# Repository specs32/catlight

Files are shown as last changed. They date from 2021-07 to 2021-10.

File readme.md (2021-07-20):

# CATLight (Creativity Art Technology)

The new and shiny Flat Flashlight, now featuring:

- ESP32-S2
- MAX77751
- SK6812 + Cree J-Series
- IMU LSM6DS3
- 3000 mAh LiPo (11.5 Wh)
- more to come

Thank you and have a nice day !

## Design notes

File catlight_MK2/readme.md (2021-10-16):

# CATLight (Creativity Art Technology)

This is MARK 2 of the new and shiny ESP32-S2 driven flat flashlight (aka flatlight)

This is a close proximity Flashlight, it has no lense to focus a beam, but it smoothly lights up a wide field around you. I find it perfect for indoor usage (searching dark drawers in the cellar and so on, but it also lights your way to the shed at night..)

Features : 
- USB-C power delivery standard realized with a MAX77751 (fast charge + PD (boost mode 5V up to 1 Amp))
- ESP32-S2 with wifi etc...
- 1.2 " TFT SPI color display
- 1 IMU LSM6DS3 or LSM6DSM .. both will work with slight changes in the initialization
- 1 CREE XLAMP with a DIO5661 flash driver and protective lens (no focus) that delivers up to 1.5 Amps into the XLAMP.. makes for a nice foto flash ..
- 16 neopixels on there 2 rows by 8.. i think it is possible to realize a POV display with it since there also is a LSM6DS3 IMU on there.
- 10 Duris high power LEDs (100mA each) this is the main light source (300 mA J-Series are no longer available.. sadly !)
- 4 TEMP sensors on the light. 2 NTCs close to critical places (XLAMP and Duris LEDS) 1 in the ESP itself and on in the IMU.
- Battery Voltage measuring (resistor divider on analog 1)

### This Revision works ! 

... with no errors as far as I can see and test (I own no OSZI ;))

There is one thing though... the Antenna matching Network works better if you put a cap in series and the coil in the first place to ground. (swap C24 with L3)

This revision works with WLED beta 2 (0.13.0-b2) there are filesystem issues, but the default install seems to work and you can save the LED settings and power off / on again and it maintains theses settings even there is no "official" support for the ESP32-S2 yet.
MAYBE I will fork and branch and modify and write a usermod for wled in the future. Maybe...
For now there is rudimentary arduino firmware in the arduino folder.
There is a platformio_override.ini in the base Folder I used to compile WLED with in code OSS with platformio under arch linux.

#### WARNING !!! WARNING !!! WARNING !!! WARNING !!! WARNING !!! WARNING !!! WARNING !!! WARNING !!! 

DO NOT put too much capacitance on the LED side, it will mess with the soft latch ! 1µF per duris LED is sufficient and works.
If you put a lot of high value CAPs on the LED side you need to lower the value of R5. (1.2KΩ with 25 µF on the LED side. Flash and array)

the duris LEDs are mosfet driven and that is their ONE and ONLY current limiter, a duty cycle of 30 % on a full lipo makes a nice bright light.
if you pull up the mosfet with 100 % duty cycle it make a smoldered PCB with the LEDs falling off and molten solder dripping everywhere... 
probably a good idea to keep that in mind when fumbling with the firmware...
___

there is a footprint for additional flash memory with a solder bridge CS0/CS1 parallel to the internal flash. if you have an ESP32-S2 without flash you can put a flash chip here (AT256Q i think) please refer to the flash compatibility list for the ESP32-S2 on the espressif website.

wifi standby time with a genuine LIPO Battery is 60+ hours

USB-C fast charging works up to 2.5 Ampere !! (almost full in 60 minutes ;))
the MAX 77751 supports pass through and power delivery, so you can charge your phne on the light in an emerrgency !

Please keep in mind that this project is my private experiment and CC-BY-NC-SA !
If you blow up your toaster .. not my fault.

the overall development cost was 600 €, the cost per CATLight (PCB + parts + 3dprint) is around 50 € assembly time is 6-8 hours if you do it 100% by hand.

Have fun emitting Bosons of differend wavelength..

made with <3 btw!

#### Special thanks to Lisa who provided all the cat drawings !!!
___
___

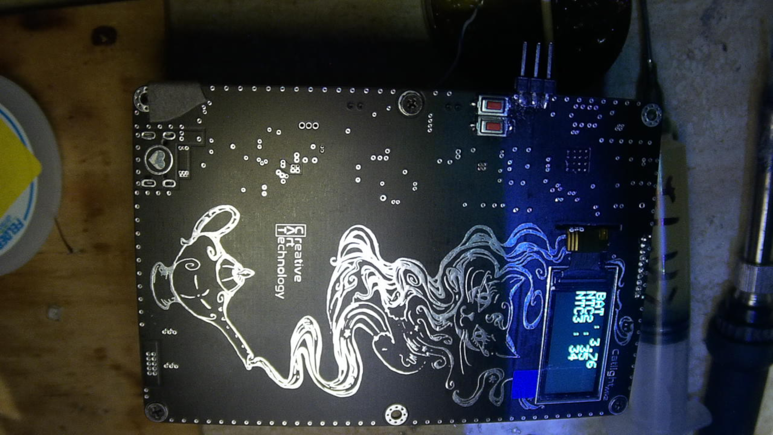
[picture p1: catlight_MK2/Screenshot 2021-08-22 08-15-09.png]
screen1

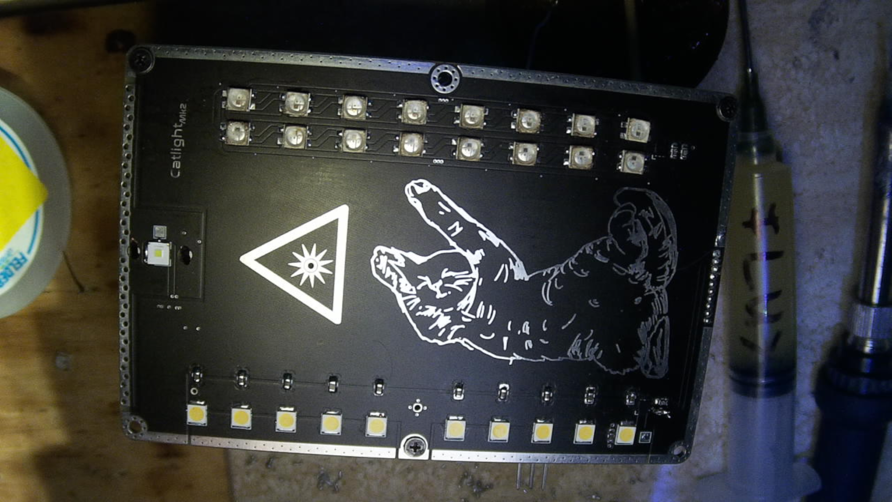
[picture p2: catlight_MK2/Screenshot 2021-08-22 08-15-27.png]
screen2

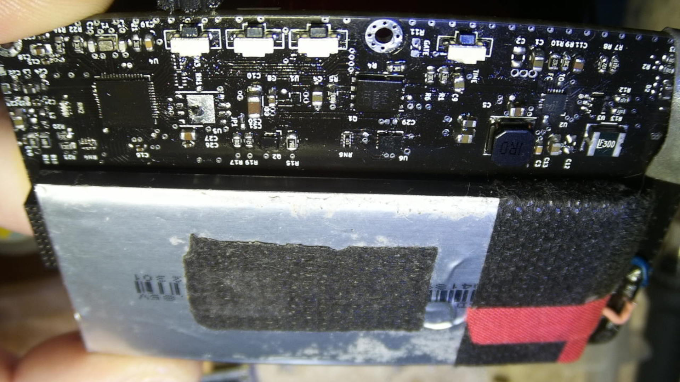
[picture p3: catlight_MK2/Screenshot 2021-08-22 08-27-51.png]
screen3

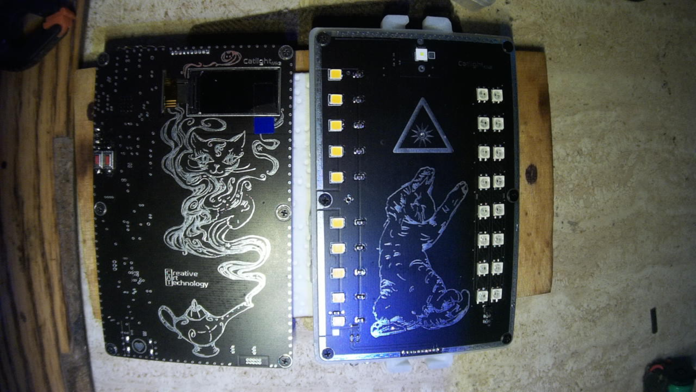
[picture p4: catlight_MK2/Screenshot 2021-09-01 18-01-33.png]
screen4


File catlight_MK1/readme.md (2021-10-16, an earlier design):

# CATLight (Creativity Art Technology)

This is MARK 1 of the new and shiny ESP32-S2 driven flat flashlight (aka flatlight)

The last flatlight revision was 19 ... I changed naming, and revision number from here on.

So this would be the flatlight REV 20

## This Revision contains multiple errors and has many features missing !!

### The first Pancake never gets right ;)

I release it anyways. Its just my dirty Sandbox to get some mud on my fingers !

thank you and have a nice day !

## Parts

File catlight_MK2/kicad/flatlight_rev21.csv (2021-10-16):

Source: | /home/jeez/Documents/kicad/PROJECTS/flatlight_rev21/flatlight_rev21.kicad_sch
Date: | Thu 26 Aug 2021 20:55:10 CEST
Tool: | Eeschema (5.99.0-11689-g04c6b79350)
Generator: | /usr/share/kicad-nightly/plugins/bom_csv_grouped_by_value_with_fp.py
Component Count: | 169
Ref | Qnty | Value | Cmp name | Footprint | Description | Vendor
BT1, | 1 | lipo_sams_BG930ABE | lipo_sams_BG930ABE | lt_foots:lipo_samsung_BG930ABE_double | Multiple-cell battery
C1, C2, C6, C12, C18, C23, C30, C31, C32, C33, C34, C35, C36, C37, C38, C39, | 16 | 10µF | C_Small | Capacitor_SMD:C_0805_2012Metric | Unpolarized capacitor, small symbol
C3, | 1 | 100nF | C | Capacitor_SMD:C_0603_1608Metric | Unpolarized capacitor
C4, C7, C8, C9, C19, C22, C27, | 7 | 1µF | C | Capacitor_SMD:C_0603_1608Metric | Unpolarized capacitor
C5, C11, | 2 | 2.2µF | C_Small | Capacitor_SMD:C_0603_1608Metric | Unpolarized capacitor, small symbol
C10, | 1 | 10µF | C_Small | Capacitor_SMD:C_1206_3216Metric_Pad1.33x1.80mm_HandSolder | Unpolarized capacitor, small symbol
C13, | 1 | 22µF | C | Capacitor_SMD:C_0805_2012Metric | Unpolarized capacitor
C14, C20, | 2 | 10pF | C_Small | Capacitor_SMD:C_0402_1005Metric | Unpolarized capacitor, small symbol
C15, C16, C21, C26, C28, C29, C49, | 7 | 100nF | C_Small | Capacitor_SMD:C_0402_1005Metric | Unpolarized capacitor, small symbol
C24, C25, | 2 | 4,7 pF | C | Capacitor_SMD:C_0402_1005Metric | Unpolarized capacitor
C46, | 1 | 22µF | C_Small | Capacitor_SMD:C_1206_3216Metric | Unpolarized capacitor, small symbol
C47, | 1 | 10µF | C_Small | Capacitor_SMD:C_1206_3216Metric | Unpolarized capacitor, small symbol
D1, | 1 | LED_ABRG | LED_ABRG | lt_foots:0606_ARGB_LED | RGB LED, anode/blue/red/green
D2, | 1 | ESD9B5.0ST5G | ESD9B5.0ST5G | Diode_SMD:D_0402_1005Metric_Pad0.77x0.64mm_HandSolder | ESD protection diode, 5.0Vrwm, SOD-923
D3, D4, D5, D6, D7, D8, D9, D10, D11, D12, D13, D14, D15, D16, D17, D18, | 16 | SK6812MINI | SK6812MINI | lt_foots:LED_SK6812MINI | RGB LED with integrated controller
D19, D20, D21, D22, D23, D24, D25, D26, D27, D28, | 10 | LED | LED | LED_SMD:LED_PLCC_2835 | Light emitting diode
D35, | 1 | LED_Cree_XPP | LED_Cree_XPP | LED_SMD:LED_Cree-XHP35
F1, | 1 | Polyfuse_Small | Polyfuse_Small | lt_foots:FUSE_littlefuse_2016-4.1x5.2mm | Resettable fuse, polymeric positive temperature coefficient, small symbol
FB1, | 1 | FerriteBead_Small | FerriteBead_Small | Resistor_SMD:R_0805_2012Metric_Pad1.20x1.40mm_HandSolder | Ferrite bead, small symbol
H1, H2, H3, H4, H5, H6, H15, H16, H17, H18, H19, H20, | 12 | MountingHole_Pad | MountingHole_Pad | MountingHole:MountingHole_2.2mm_M2_Pad_Via | Mounting Hole with connection
H7, | 1 | thole1 | MountingHole_Pad | lt_foots:plated_hole_1mm | Mounting Hole with connection
H14, | 1 | thole8 | MountingHole_Pad | lt_foots:plated_hole_1mm | Mounting Hole with connection
J1, | 1 | USB_C_Receptacle_USB2.0 | USB_C_Receptacle_USB2.0 | Connector_USB:USB_C_Receptacle_JAE_DX07S016JA1R1500 | USB 2.0-only Type-C Receptacle connector
J2, | 1 | G-T-R | Conn_01x03_Male | lt_foots:01x03_smd_1mmx2mm_pad | Generic connector, single row, 01x03, script generated (kicad-library-utils/schlib/autogen/connector/)
J3, | 1 | B2B_eside | Conn_01x10 | Connector_PinSocket_1.27mm:PinSocket_1x10_P1.27mm_Vertical | Generic connector, single row, 01x10, script generated (kicad-library-utils/schlib/autogen/connector/)
J4, | 1 | B2B_ledside | Conn_01x10 | Connector_PinHeader_1.27mm:PinHeader_1x10_P1.27mm_Vertical | Generic connector, single row, 01x10, script generated (kicad-library-utils/schlib/autogen/connector/)
JP1, | 1 | SolderJumper_3_Open | SolderJumper_3_Open | lt_foots:microbridge | Solder Jumper, 3-pole, open
L1, | 1 | 1µH | L_Ferrite_Small | Inductor_SMD:L_Taiyo-Yuden_NR-60xx | Inductor with ferrite core, small symbol
L2, | 1 | 1µH | L_Small | Inductor_SMD:L_0603_1608Metric | Inductor, small symbol
L3, | 1 | 1.8 nH | L_Small | Inductor_SMD:L_0603_1608Metric | Inductor, small symbol
L4, | 1 | 1µH | L_Ferrite_Small | Inductor_SMD:L_1008_2520Metric_Pad1.43x2.20mm_HandSolder | Inductor with ferrite core, small symbol
lense1, | 1 | Lense_Mount | heart | lt_foots:LENS_LEDIL_C12491_siri_diff
logo1, | 1 | logo_qrtag | logo_serialnumber | lt_foots:logo_QR_url_git_catlight
logo2, logo5, | 2 | logo_JLC | logo_contact | lt_foots:JLC-SERIAL
logo4, | 1 | logo_TIGER | logo_contact | lt_foots:LOGO_Tiger_1
logo6, | 1 | logo_esd | logo_contact | Symbol:ESD-Logo_6.6x6mm_SilkScreen
logo7, | 1 | logo_FIREFLY_lrg | logo_serialnumber | lt_foots:logo_firefly_40mm
logo8, | 1 | logo_heart | logo_contact | lt_foots:logo_heart3
logo9, | 1 | logo_LWarn | logo_serialnumber | lt_foots:logo_lightwarn_large
logo10, | 1 | logo_CATLIGHT | logo_contact | lt_foots:logo_catlightMK2_small
Q1, | 1 | DMC1016UPD | DMC1016UPD | lt_foots:PowerDI5060-8
Q2, Q3, Q4, | 3 | DMN2022-UFDF7 | DMN2022-UFDF7 | lt_foots:U-DFN2020-6 (Type F) | 0.2A Id, 200V Vds, N-Channel MOSFET, 2.6V Logic Level, TO-92
R1, R4, R14, R21, R22, | 5 | 10kΩ | R_Small | Resistor_SMD:R_0603_1608Metric | Resistor, small symbol
R2, R3, | 2 | 1KΩ | R_Small | Resistor_SMD:R_0603_1608Metric | Resistor, small symbol
R5, | 1 | 10kΩ (depending on caps) | R | Resistor_SMD:R_0603_1608Metric | Resistor
R6, | 1 | 100kΩ | R | Resistor_SMD:R_0603_1608Metric | Resistor
R7, R8, | 2 | 20kΩ | R_Small | Resistor_SMD:R_0603_1608Metric | Resistor, small symbol
R9, | 1 | 10KΩ(150mA_TO) | R_Small | Resistor_SMD:R_0603_1608Metric | Resistor, small symbol
R10, | 1 | 10KΩ(1.5A_FC) | R_Small | Resistor_SMD:R_0603_1608Metric | Resistor, small symbol
R11, | 1 | 0 Ω | R | Resistor_SMD:R_0603_1608Metric | Resistor
R12, R13, | 2 | 22Ω | R_Small | Resistor_SMD:R_0603_1608Metric | Resistor, small symbol
R15, | 1 | 14Ω | R | Resistor_SMD:R_0805_2012Metric | Resistor
R16, R18, R19, R25, R29, | 5 | 1MΩ | R | Resistor_SMD:R_0603_1608Metric | Resistor
R17, R24, R28, | 3 | 1kΩ | R | Resistor_SMD:R_0603_1608Metric | Resistor
R20, R23, | 2 | 10 kΩ | R | Resistor_SMD:R_0603_1608Metric | Resistor
R26, R27, | 2 | NTC 10 kΩ | R | Resistor_SMD:R_0603_1608Metric | Resistor
R30, | 1 | 37.5kΩ | R | Resistor_SMD:R_0603_1608Metric | Resistor
R31, | 1 | 12kΩ | R | Resistor_SMD:R_0603_1608Metric | Resistor
RN1, RN2, RN3, | 3 | 0Ω | R_Pack04 | lt_foots:R_Array_Concave_4x0402 | 4 resistor network, parallel topology
RN4, | 1 | 1kΩ | R_Pack04 | lt_foots:R_Array_Concave_4x0402 | 4 resistor network, parallel topology
RN6, | 1 | 10KΩ | R_Pack04 | lt_foots:R_Array_Concave_4x0402 | 4 resistor network, parallel topology
SW1, SW4, SW5, SW6, | 4 | BTN_PWR | nano_switc_with_mnt_pads-nicos-parts | lt_foots:white_nano_smd_switch
SW2, | 1 | BT | SW_Push | lt_foots:SW_SPST_EVQPE1 | Push button switch, generic, two pins
SW3, | 1 | RST | SW_Push | lt_foots:SW_SPST_EVQPE1 | Push button switch, generic, two pins
TFT1, | 1 | OLED_ST7735_0.9inch_SPI_13pin | OLED_ST7735_0.9inch_SPI_13pin | lt_foots:TFT_ST7735_0,96_160x80_folded
TP6, | 1 | ANT_H | TestPoint | TestPoint:TestPoint_Pad_1.0x1.0mm | test point
TP8, | 1 | ANT_GND | TestPoint | TestPoint:TestPoint_Pad_1.0x1.0mm | test point
TP9, TP10, | 2 | TestPoint | TestPoint | TestPoint:TestPoint_Pad_1.5x1.5mm | test point
TP11, TP12, | 2 | GND | TestPoint | TestPoint:TestPoint_Pad_1.0x1.0mm | test point
TP13, TP14, | 2 | +BATT | TestPoint | TestPoint:TestPoint_Pad_1.0x1.0mm | test point
U1, | 1 | NCP167-XDFN4 | NCP167-XDFN4 | Package_DFN_QFN:UDFN-4-1EP_1x1mm_P0.65mm_EP0.48x0.48mm
U2, | 1 | MAX77751 | MAX77751 | lt_foots:max77751
U3, | 1 | USBLC6-4SC6 | USBLC6-4SC6 | Package_TO_SOT_SMD:SOT-23-6 | Very low capacitance ESD protection diode, 4 data-line, SOT-23-6
U4, | 1 | ESP32-S2 | ESP32-S2 | lt_foots:QFN-56-1EP_7x7mm_P0.4mm_EP5.6x5.6mm_ThermalVias | RF Module, ESP32 SoC, Wi-Fi 802.11b/g/n, Bluetooth, BLE, 32-bit, 2.7-3.6V, external antenna, QFN-48
U5, | 1 | AT25xxx-MA | AT25xxx-MA | Package_SON:WSON-8-1EP_6x5mm_P1.27mm_EP3.4x4.3mm | Microchip SPI Serial EEPROM, DFN8
U6, | 1 | LSM6DS3 | LSM6DS3 | Package_LGA:Bosch_LGA-14_3x2.5mm_P0.5mm | I2C/SPI, iNEMO inertial module: always-on 3D accelerometer and 3D gyroscope
U7, | 1 | LDRV_DIO5180 | LDRV_DIO5180 | lt_foots:DFN-14-2x3mm
Y1, | 1 | 40MHz | Crystal_GND24_Small | lt_foots:Crystal_SMD_2016-4Pin_2.0x1.6mm_smallpads | Four pin crystal, GND on pins 2 and 4, small symbol

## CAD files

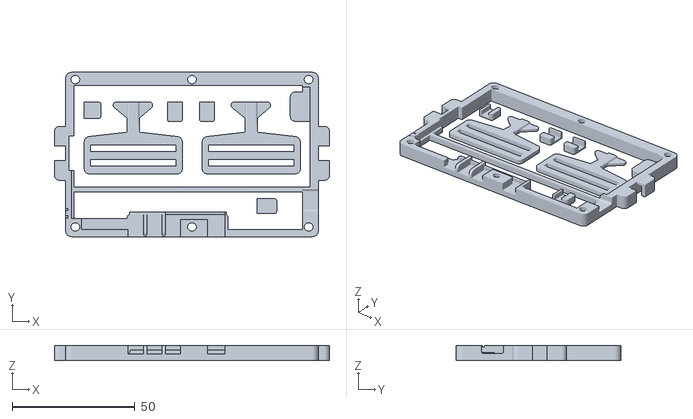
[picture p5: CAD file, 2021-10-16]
catlight_MK2/blender/catlight_frame_30.stl
112.0 x 67.0 x 6.00

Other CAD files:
catlight_MK2/blender/catlight_frame_30.blend

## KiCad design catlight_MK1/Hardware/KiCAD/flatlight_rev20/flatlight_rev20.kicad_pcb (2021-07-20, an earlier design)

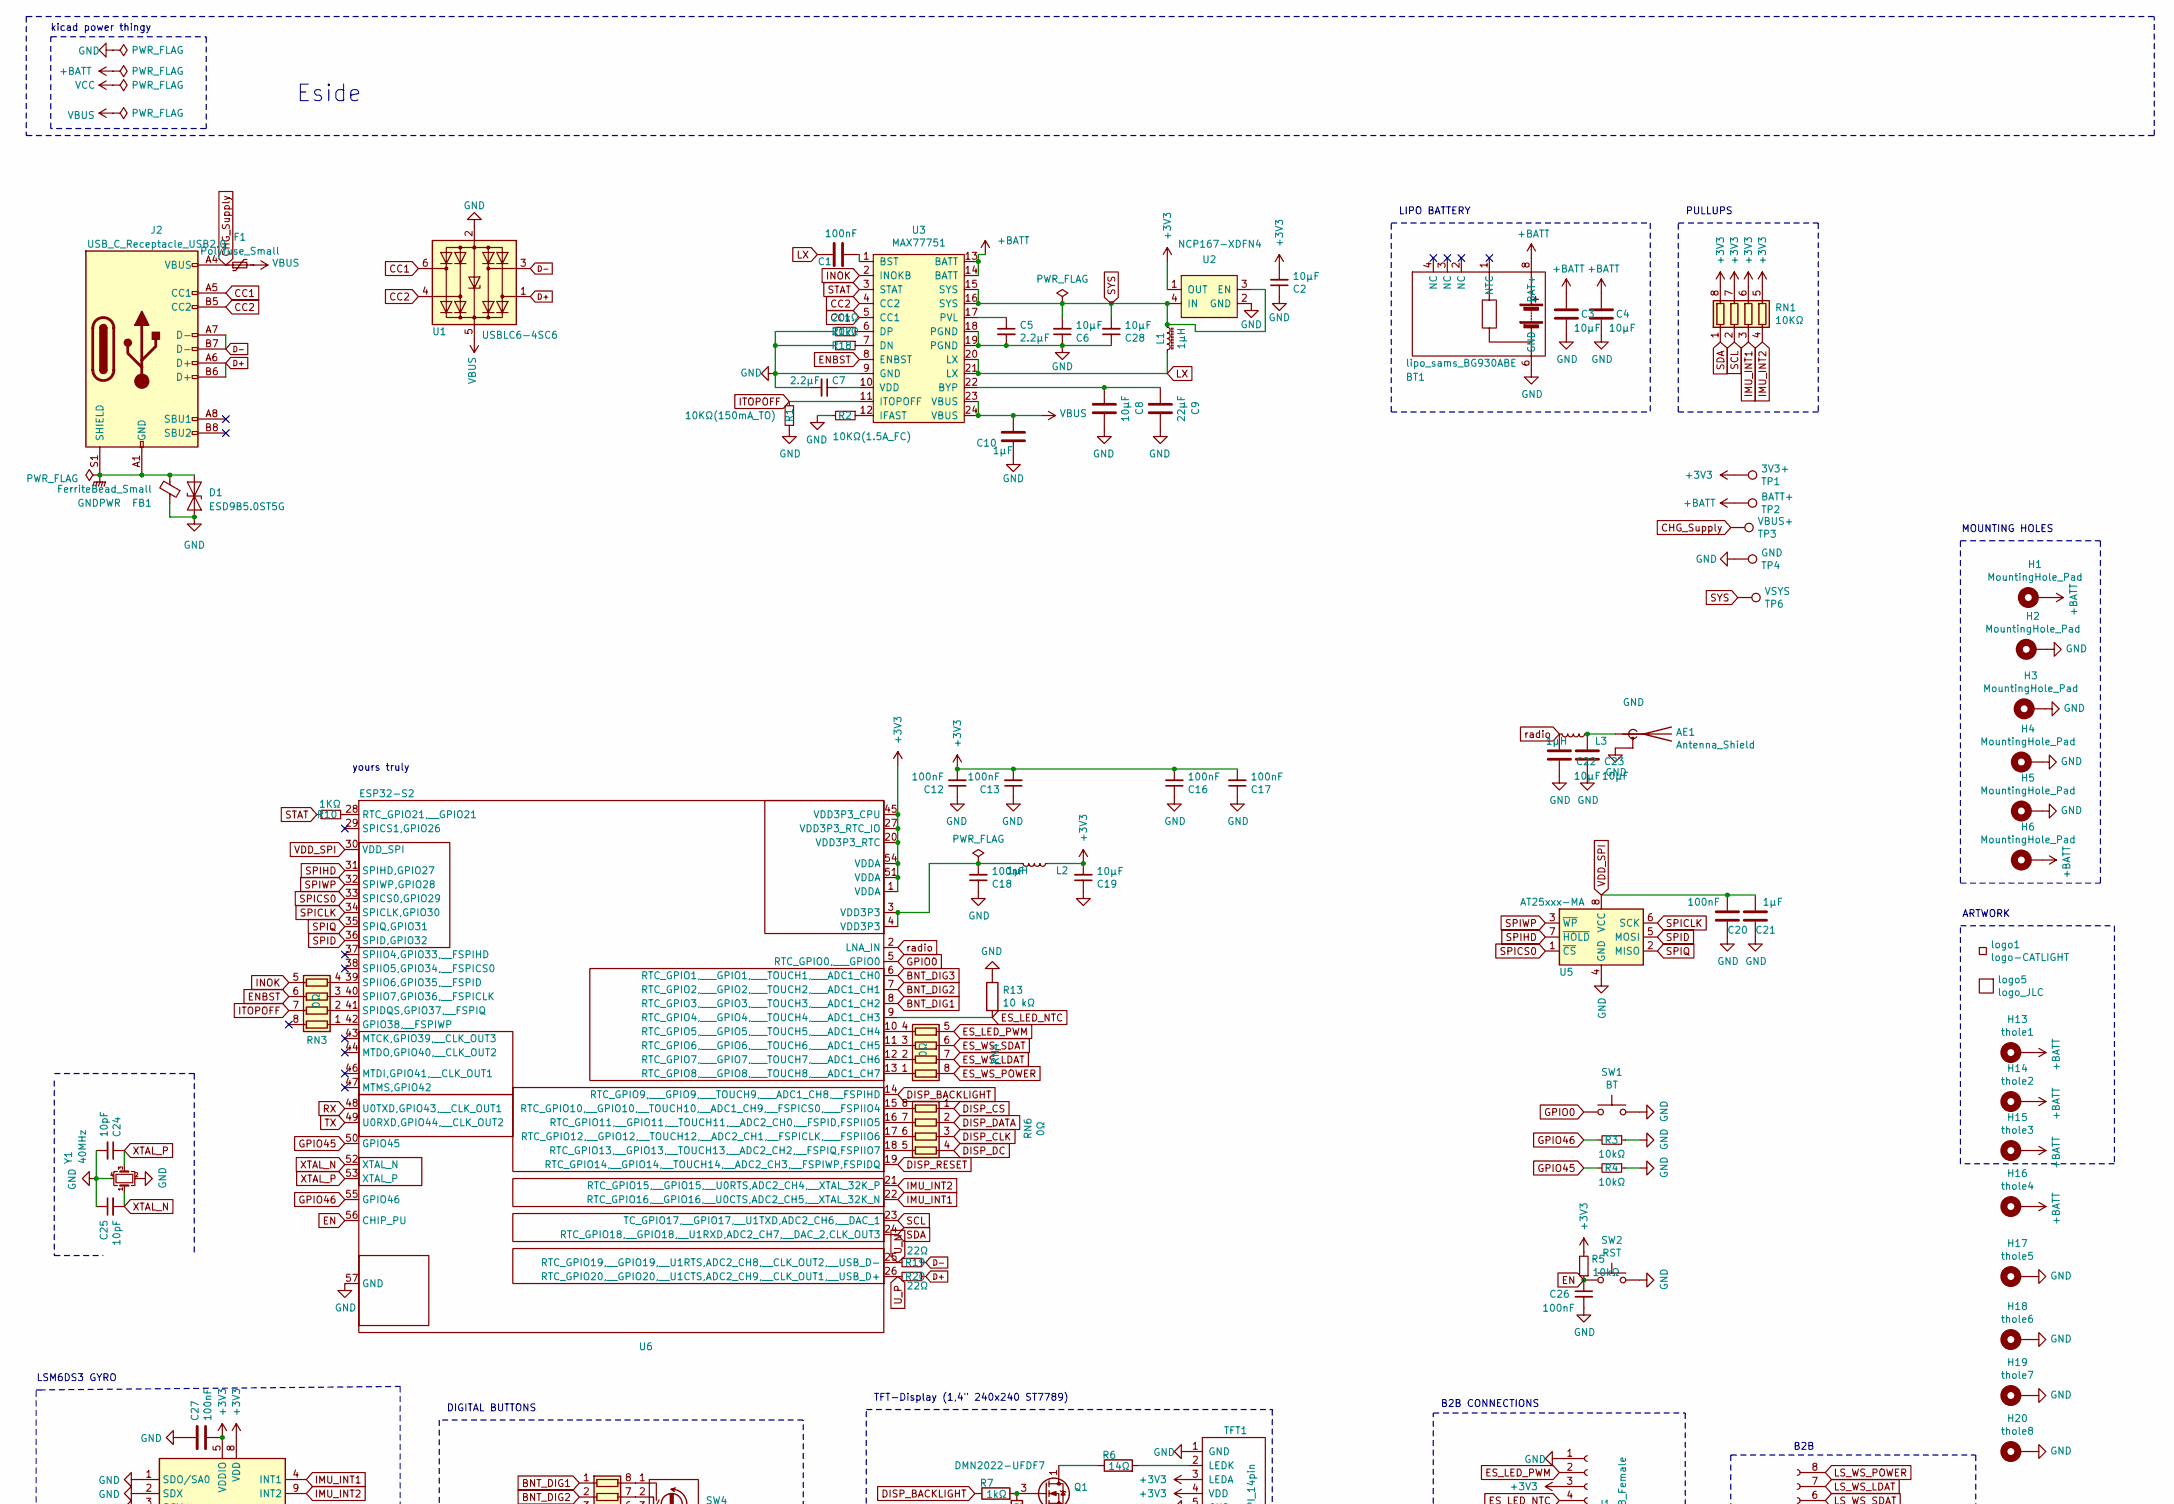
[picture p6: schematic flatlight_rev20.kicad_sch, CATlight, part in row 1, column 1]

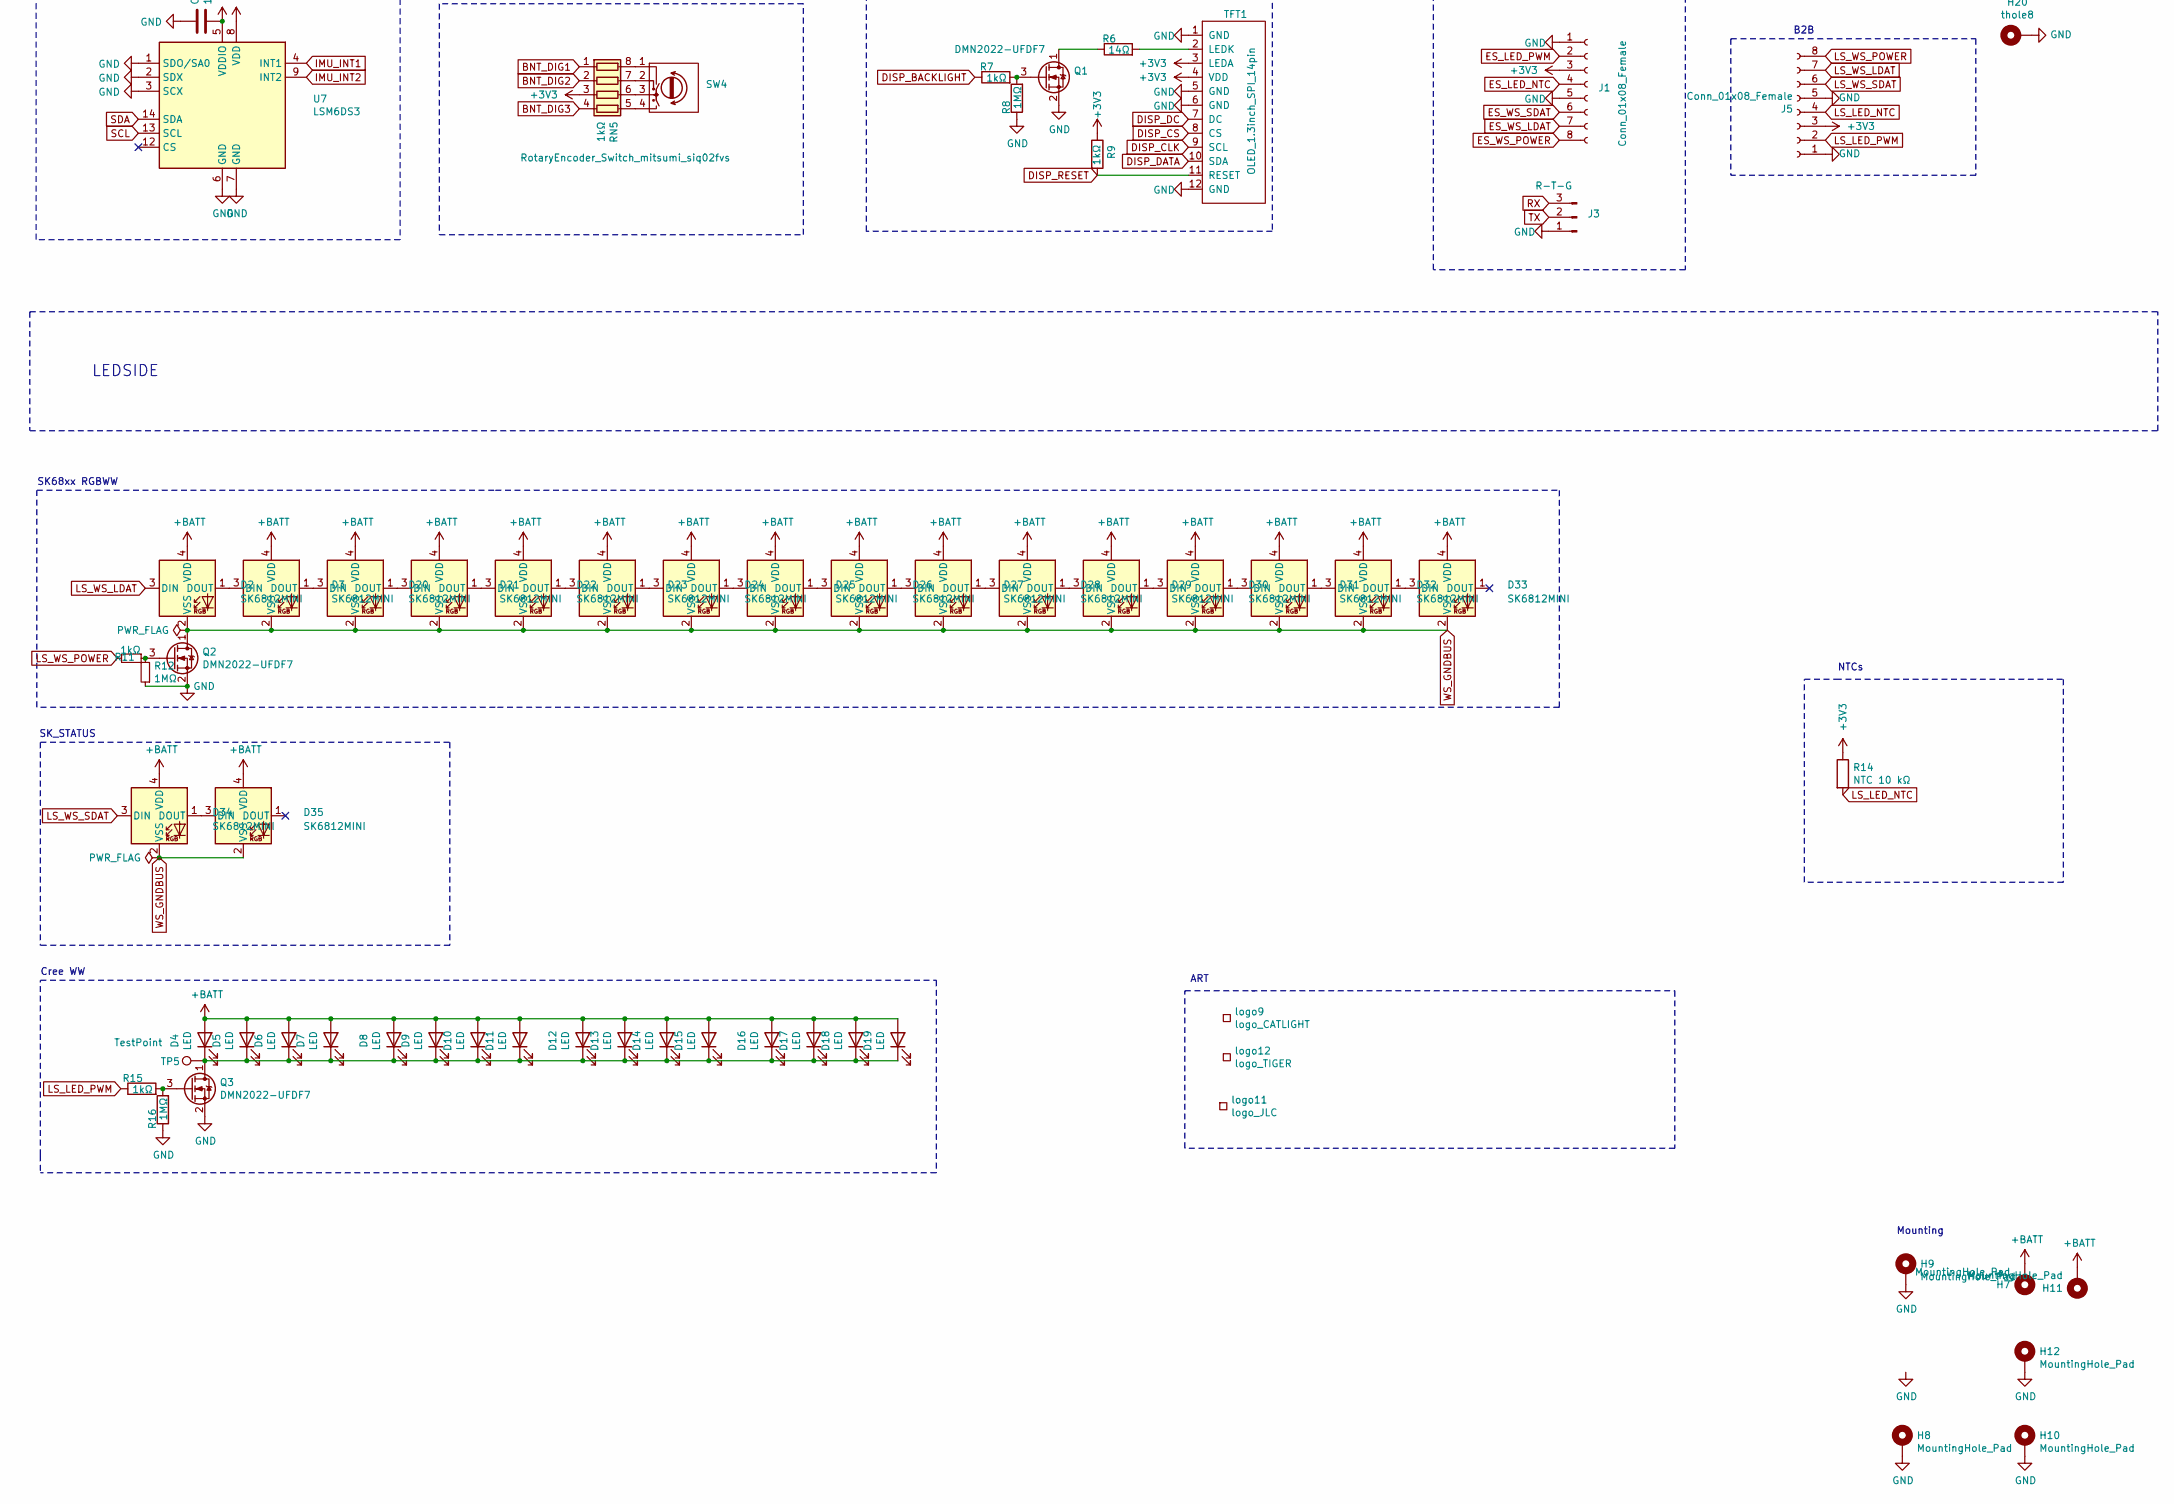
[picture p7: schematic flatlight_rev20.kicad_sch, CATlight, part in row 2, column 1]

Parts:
AE1: Antenna_Shield; Texas_SWRA117D_2.4GHz_Left
BT1: lipo_sams_BG930ABE; lipo_samsung_BG930ABE_double
C1: 100nF; C_0603_1608Metric
C2, C3, C4, C6, C8, C28: 10µF; C_0805_2012Metric
C5, C7: 2.2µF; C_0805_2012Metric
C9: 22µF; C_1210_3225Metric
C10: 1µF; C_0805_2012Metric
C12, C13, C16, C17, C18, C20, C26, C27: 100nF; C_0402_1005Metric
C19, C22, C23: 10µF; C_0603_1608Metric
C21: 1µF; C_0603_1608Metric
C24, C25: 10pF; C_0603_1608Metric
D1: ESD9B5.0ST5G; D_0402_1005Metric_Pad0.77x0.64mm_HandSolder
D2, D20, D21, D22, D23, D24, D25, D26, D27, D28, D29, D30, D31, D32, D33, D34, D35: SK6812MINI; LED_SK6812MINI
D3: SK6812MINI; LED_SK6812MINI_PLCC4_3.5x3.5mm_P1.75mm
D4, D5, D6, D7, D8, D9, D10, D11, D12, D13, D14, D15, D16, D17, D18, D19: LED; LED_Cree-J-Series
F1: Polyfuse_Small; R_0805_2012Metric_Pad1.20x1.40mm_HandSolder
FB1: FerriteBead_Small; R_0805_2012Metric_Pad1.20x1.40mm_HandSolder
H1, H2, H3, H4, H5, H6, H7, H8, H9, H10, H11, H12: MountingHole_Pad; MountingHole_2.2mm_M2_Pad_Via
H13: thole1; plated_hole_1mm
H14: thole2; plated_hole_1mm
H15: thole3; plated_hole_1mm
H16: thole4; plated_hole_1mm
H17: thole5; plated_hole_1mm
H18: thole6; plated_hole_1mm
H19: thole7; plated_hole_1mm
H20: thole8; plated_hole_1mm
J1, J5: Conn_01x08_Female; PinHeader_1x08_P2.00mm_Vertical
J2: USB_C_Receptacle_USB2.0; USB_C_Receptacle_JAE_DX07S016JA1R1500
J3: R-T-G; 01x03_smd_1mmx2mm_pad
L1: 1µH; L_Wuerth_MAPI-4030
L2, L3: 1µH; L_0603_1608Metric
Q1, Q2, Q3: DMN2022-UFDF7; U-DFN2020-6 (Type F)
R1: 10KΩ(150mA_TO); R_0603_1608Metric
R2: 10KΩ(1.5A_FC); R_0603_1608Metric
R3, R4, R5: 10kΩ; R_0603_1608Metric
R6: 14Ω; R_0603_1608Metric
R7, R9, R11, R15: 1kΩ; R_0603_1608Metric
R8, R12, R16: 1MΩ; R_0603_1608Metric
R10: 1KΩ; R_0603_1608Metric
R13: 10 kΩ; R_0603_1608Metric
R14: NTC 10 kΩ; R_0603_1608Metric
R17, R18: 20kΩ; R_0603_1608Metric
R19, R20: 22Ω; R_0603_1608Metric
RN1: 10KΩ; R_Array_Concave_4x0402
RN3, RN4, RN6: 0Ω; R_Array_Concave_4x0402
RN5: 1kΩ; R_Array_Concave_4x0402
SW1: BT; SW_SPST_B3U-1000P
SW2: RST; SW_SPST_B3U-1000P
SW4: RotaryEncoder_Switch_mitsumi_siq02fvs; ROTARY_ENCODER_SIQ_02FVS
TFT1: OLED_1.3inch_SPI_14pin; TFT_1.3inch_spi_12pin_240x240RGB_flat
TP1: 3V3+; TestPoint_Pad_1.0x1.0mm
TP2: BATT+; TestPoint_Pad_1.0x1.0mm
TP3: VBUS+; TestPoint_Pad_1.0x1.0mm
TP4: GND; TestPoint_Pad_1.0x1.0mm
TP5: TestPoint; TestPoint_Pad_1.5x1.5mm
TP6: VSYS; TestPoint_Pad_1.0x1.0mm
U1: USBLC6-4SC6; SOT-23-6
U2: NCP167-XDFN4; UDFN-4-1EP_1x1mm_P0.65mm_EP0.48x0.48mm
U3: MAX77751; max77751
U5: AT25xxx-MA; DFN-8-1EP_3x2mm_P0.5mm_EP1.75x1.45mm
U6: ESP32-S2; QFN-56-1EP_7x7mm_P0.4mm_EP5.6x5.6mm_ThermalVias
U7: LSM6DS3; Bosch_LGA-14_3x2.5mm_P0.5mm
Y1: 40MHz; Crystal_SMD_2520-4Pin_2.5x2.0mm
logo1: logo-CATLIGHT; LOGO_CATLIGHT_4
logo5, logo11: logo_JLC; JLC-SERIAL
logo9: logo_CATLIGHT; LOGO_CATLIGHT_4_small
logo12: logo_TIGER; LOGO_Tiger_1

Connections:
+3V3: C2.2, C12.2, C13.2, C16.2, C17.2, C19.2, C27.2, J1.3, J5.3, L2.1, R5.2, R9.1, R14.1, RN1.5 (R4.2), RN1.6 (R3.2), RN1.7 (R2.2), RN1.8 (R1.2), RN5.3 (R3.1), TFT1.3 (LEDA), TFT1.4 (VDD), TP1.1, U2.1 (OUT), U6.1 (VDDA), U6.20 (VDD3P3_RTC), U6.27 (VDD3P3_RTC_IO), U6.45 (VDD3P3_CPU), U6.51 (VDDA), U6.54 (VDDA), U7.5 (VDDIO), U7.8 (VDD)
+BATT: BT1.7 (BAT+), BT1.8 (BAT+), C3.1, C4.1, D2.4 (VDD), D3.4 (VDD), D4.2 (A), D5.2 (A), D6.2 (A), D7.2 (A), D8.2 (A), D9.2 (A), D10.2 (A), D11.2 (A), D12.2 (A), D13.2 (A), D14.2 (A), D15.2 (A), D16.2 (A), D17.2 (A), D18.2 (A), D19.2 (A), D20.4 (VDD), D21.4 (VDD), D22.4 (VDD), D23.4 (VDD), D24.4 (VDD), D25.4 (VDD), D26.4 (VDD), D27.4 (VDD), D28.4 (VDD), D29.4 (VDD), D30.4 (VDD), D31.4 (VDD), D32.4 (VDD), D33.4 (VDD), D34.4 (VDD), D35.4 (VDD), H1.1, H6.1, H7.1, H11.1, H13.1, H14.1, H15.1, H16.1, TP2.1, U3.13 (BATT), U3.14 (BATT)
BNT_DIG1: RN5.1 (R1.1), U6.8 (RTC_GPIO3,___GPIO3,___TOUCH3,___ADC1_CH2)
BNT_DIG2: RN5.2 (R2.1), U6.7 (RTC_GPIO2,___GPIO2,___TOUCH2,___ADC1_CH1)
BNT_DIG3: RN5.4 (R4.1), U6.6 (RTC_GPIO1,___GPIO1,___TOUCH1,___ADC1_CH0)
CC1: J2.A5 (CC1), U1.6 (I/O4), U3.5 (CC1)
CC2: J2.B5 (CC2), U1.4 (I/O3), U3.4 (CC2)
CHG_Supply: F1.1, J2.A4 (VBUS), J2.A9 (VBUS), J2.B4 (VBUS), J2.B9 (VBUS), TP3.1
D+: J2.A6 (D+), J2.B6 (D+), R20.1, U1.1 (I/O1)
D-: J2.A7 (D-), J2.B7 (D-), R19.1, U1.3 (I/O2)
DISP_BACKLIGHT: R7.1, U6.14 (RTC_GPIO9,___GPIO9,___TOUCH9,___ADC1_CH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)
DISP_CLK: RN6.3 (R3.1), TFT1.9 (SCL)
DISP_CS: RN6.1 (R1.1), TFT1.8 (CS)
DISP_DATA: RN6.2 (R2.1), TFT1.10 (SDA)
DISP_DC: RN6.4 (R4.1), TFT1.7 (DC)
DISP_RESET: R9.2, TFT1.11 (RESET), U6.19 (RTC_GPIO14,__GPIO14,__TOUCH14,__ADC2_CH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)
EN: C26.1, R5.1, SW2.1, U6.56 (CHIP_PU)
ENBST: RN3.6 (R3.2), U3.8 (ENBST)
ES_LED_NTC: J1.4, R13.2, U6.9 (RTC_GPIO4,___GPIO4,___TOUCH4,___ADC1_CH3)
ES_LED_PWM: J1.2, RN4.5 (R4.2)
ES_WS_LDAT: J1.7, RN4.7 (R2.2)
ES_WS_POWER: J1.8, RN4.8 (R1.2)
ES_WS_SDAT: J1.6, RN4.6 (R3.2)
GND: AE1.2 (Shield), BT1.5 (GND), BT1.6 (GND), C2.1, C3.2, C4.2, C5.2, C6.1, C7.2, C8.2, C9.2, C10.1, C12.1, C13.1, C16.1, C17.1, C18.1, C19.1, C20.1, C21.1, C22.1, C23.1, C24.2, C25.1, C26.2, C27.1, C28.1, D1.1 (A1), FB1.1, H2.1, H3.1, H4.1, H5.1, H8.1, H9.1, H10.1, H12.1, H17.1, H18.1, H19.1, H20.1, J1.1, J1.5, J3.1, J5.1, J5.5, Q1.2 (S), Q2.2 (S), Q3.2 (S), R1.1, R2.2, R3.1, R4.1, R8.1, R12.1, R13.1, R16.1, R17.2, R18.2, SW1.2, SW2.2, TFT1.1 (GND), TFT1.5 (GND), TFT1.6 (GND), TFT1.12 (GND), TP4.1, U1.2 (GND), U2.2 (GND), U2.5 (GND), U3.9 (GND), U3.18 (PGND), U3.19 (PGND), U5.4 (GND), U5.9 (GND), U6.57 (GND), U7.1 (SDO/SA0), U7.2 (SDX), U7.3 (SCX), U7.6 (GND), U7.7 (GND), Y1.2, Y1.4
GNDPWR: D1.2 (A2), FB1.2, J2.A1 (GND), J2.A12 (GND), J2.B1 (GND), J2.B12 (GND), J2.S1 (SHIELD)
GPIO0: SW1.1, U6.5 (RTC_GPIO0,___GPIO0)
GPIO45: R4.2, U6.50 (GPIO45)
GPIO46: R3.2, U6.55 (GPIO46)
IMU_INT1: RN1.3 (R3.1), U6.22 (RTC_GPIO16,__GPIO16,__U0CTS,ADC2_CH5,__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), U7.4 (INT1)
IMU_INT2: RN1.4 (R4.1), U6.21 (RTC_GPIO15,__GPIO15,__U0RTS,ADC2_CH4,__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), U7.9 (INT2)
INOK: RN3.5 (R4.2), U3.2 (INOKB)
ITOPOFF: R1.2, RN3.7 (R2.2), U3.11 (ITOPOFF)
LS_LED_NTC: J5.4, R14.2
LS_LED_PWM: J5.2, R15.1
LS_WS_LDAT: D2.3 (DIN), J5.7
LS_WS_POWER: J5.8, R11.2
LS_WS_SDAT: D34.3 (DIN), J5.6
LX: C1.2, L1.2, U3.20 (LX), U3.21 (LX)
unnamed: AE1.1 (A), C23.2, L3.1
unnamed: C1.1, U3.1 (BST)
unnamed: C5.1, U3.17 (PVL)
unnamed: C7.1, U3.10 (VDD)
unnamed: C8.1, C9.1, U3.22 (BYP)
unnamed: C18.2, L2.2, U6.3 (VDD3P3), U6.4 (VDD3P3)
unnamed: D2.1 (DOUT), D3.3 (DIN)
unnamed: D4.1 (K), D5.1 (K), D6.1 (K), D7.1 (K), D8.1 (K), D9.1 (K), D10.1 (K), D11.1 (K), D12.1 (K), D13.1 (K), D14.1 (K), D15.1 (K), D16.1 (K), D17.1 (K), D18.1 (K), D19.1 (K), Q3.1 (D), TP5.1
unnamed: D20.1 (DOUT), D21.3 (DIN)
unnamed: D3.1 (DOUT), D20.3 (DIN)
unnamed: D21.1 (DOUT), D22.3 (DIN)
unnamed: D22.1 (DOUT), D23.3 (DIN)
unnamed: D23.1 (DOUT), D24.3 (DIN)
unnamed: D24.1 (DOUT), D25.3 (DIN)
unnamed: D25.1 (DOUT), D26.3 (DIN)
unnamed: D26.1 (DOUT), D27.3 (DIN)
unnamed: D27.1 (DOUT), D28.3 (DIN)
unnamed: D28.1 (DOUT), D29.3 (DIN)
unnamed: D29.1 (DOUT), D30.3 (DIN)
unnamed: D30.1 (DOUT), D31.3 (DIN)
unnamed: D31.1 (DOUT), D32.3 (DIN)
unnamed: D32.1 (DOUT), D33.3 (DIN)
unnamed: D34.1 (DOUT), D35.3 (DIN)
unnamed: Q1.1 (D), R6.1
unnamed: Q1.3 (G), R7.2, R8.2
unnamed: Q2.3 (G), R11.1, R12.2
unnamed: Q3.3 (G), R15.2, R16.2
unnamed: R2.1, U3.12 (IFAST)
unnamed: R6.2, TFT1.2 (LEDK)
unnamed: R10.1, U6.28 (RTC_GPIO21,__GPIO21)
unnamed: R17.1, U3.6 (DP)
unnamed: R18.1, U3.7 (DN)
unnamed: RN3.1 (R1.1), U6.42 (GPIO38,__FSPIWP)
unnamed: RN3.2 (R2.1), U6.41 (SPIDQS,GPIO37,__FSPIQ)
unnamed: RN3.3 (R3.1), U6.40 (SPIIO7,GPIO36,__FSPICLK)
unnamed: RN3.4 (R4.1), U6.39 (SPIIO6,GPIO35,__FSPID)
unnamed: RN4.1 (R1.1), U6.13 (RTC_GPIO8,___GPIO8,___TOUCH8,___ADC1_CH7)
unnamed: RN4.2 (R2.1), U6.12 (RTC_GPIO7,___GPIO7,___TOUCH7,___ADC1_CH6)
unnamed: RN4.3 (R3.1), U6.11 (RTC_GPIO6,___GPIO6,___TOUCH6,___ADC1_CH5)
unnamed: RN4.4 (R4.1), U6.10 (RTC_GPIO5,___GPIO5,___TOUCH5,___ADC1_CH4)
unnamed: RN5.5 (R4.2), SW4.4 (B)
unnamed: RN5.6 (R3.2), SW4.3 (C)
unnamed: RN5.7 (R2.2), SW4.2 (S)
unnamed: RN5.8 (R1.2), SW4.1 (A)
unnamed: RN6.5 (R4.2), U6.18 (RTC_GPIO13,__GPIO13,__TOUCH13,__ADC2_CH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)
unnamed: RN6.6 (R3.2), U6.17 (RTC_GPIO12,__GPIO12,__TOUCH12,__ADC2_CH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)
unnamed: RN6.7 (R2.2), U6.16 (RTC_GPIO11,__GPIO11,__TOUCH11,__ADC2_CH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)
unnamed: RN6.8 (R1.2), U6.15 (RTC_GPIO10,__GPIO10,__TOUCH10,__ADC1_CH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)
RX: J3.3, U6.48 (U0TXD,GPIO43,__CLK_OUT1)
SCL: RN1.2 (R2.1), U6.23 (TC_GPIO17,__GPIO17,__U1TXD,ADC2_CH6,__D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), U7.13 (SCL)
SDA: RN1.1 (R1.1), U6.24 (RTC_GPIO18,__GPIO18,__U1RXD,ADC2_CH7,__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), U7.14 (SDA)
SPICLK: U5.6 (SCK), U6.34 (SPICLK,GPIO30)
SPICS0: U5.1 (~CS), U6.33 (SPICS0,GPIO29)
SPID: U5.5 (MOSI), U6.36 (SPID,GPIO32)
SPIHD: U5.7 (~HOLD), U6.31 (SPIHD,GPIO27)
SPIQ: U5.2 (MISO), U6.35 (SPIQ,GPIO31)
SPIWP: U5.3 (~WP), U6.32 (SPIWP,GPIO28)
STAT: R10.2, U3.3 (STAT)
SYS: C6.2, C28.2, L1.1, TP6.1, U2.3 (EN), U2.4 (IN), U3.15 (SYS), U3.16 (SYS)
TX: J3.2, U6.49 (U0RXD,GPIO44,__CLK_OUT2)
U_N: R19.2, U6.25 (RTC_GPIO19,__GPIO19,__U1RTS,ADC2_CH8,__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)
U_P: R20.2, U6.26 (RTC_GPIO20,__GPIO20,__U1CTS,ADC2_CH9,__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)
VBUS: C10.2, F1.2, U1.5 (VBUS), U3.23 (VBUS), U3.24 (VBUS)
VDD_SPI: C20.2, C21.2, U5.8 (VCC), U6.30 (VDD_SPI)
WS_GNDBUS: D2.2 (VSS), D3.2 (VSS), D20.2 (VSS), D21.2 (VSS), D22.2 (VSS), D23.2 (VSS), D24.2 (VSS), D25.2 (VSS), D26.2 (VSS), D27.2 (VSS), D28.2 (VSS), D29.2 (VSS), D30.2 (VSS), D31.2 (VSS), D32.2 (VSS), D33.2 (VSS), D34.2 (VSS), D35.2 (VSS), Q2.1 (D)
XTAL_N: C25.2, U6.52 (XTAL_N), Y1.1
XTAL_P: C24.1, U6.53 (XTAL_P), Y1.3
radio: C22.2, L3.2, U6.2 (LNA_IN)

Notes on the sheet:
LSM6DS3 GYRO
SK68xx RGBWW
kicad power thingy
Cree WW
SK_STATUS
LEDSIDE
yours truly
Eside
DIGITAL BUTTONS
TFT-Display (1,4" 240x240 ST7789)
ART
LIPO BATTERY
B2B CONNECTIONS
PULLUPS
B2B
NTCs
Mounting
MOUNTING HOLES
ARTWORK

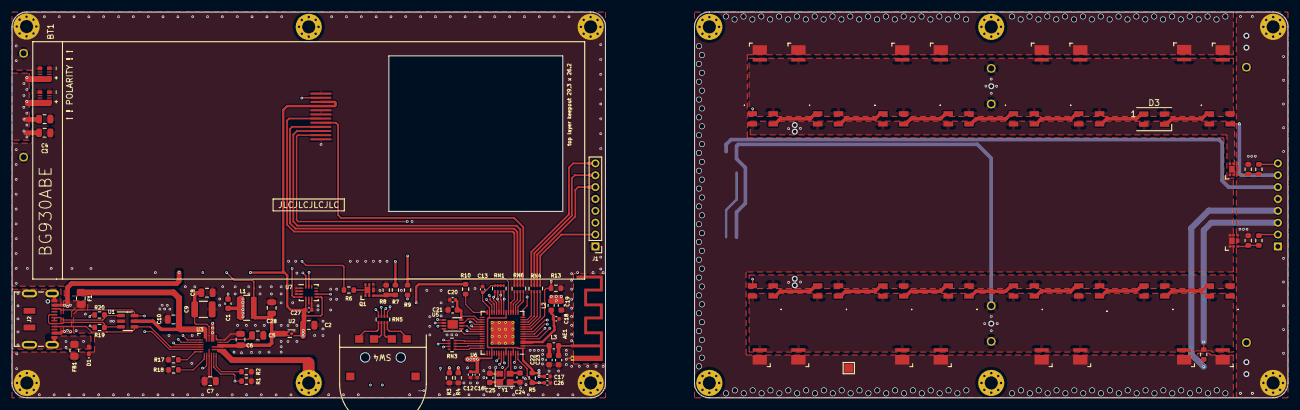
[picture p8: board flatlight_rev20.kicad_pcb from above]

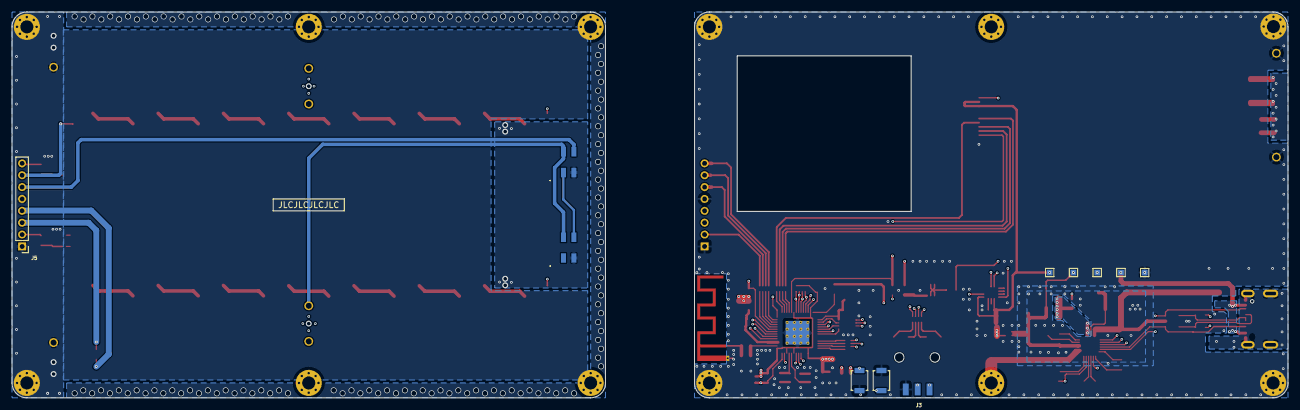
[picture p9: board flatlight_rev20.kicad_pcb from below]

Board: 4 copper layers, 215.0 x 65.0 mm, 141 parts (15 on the bottom side), 106 nets.

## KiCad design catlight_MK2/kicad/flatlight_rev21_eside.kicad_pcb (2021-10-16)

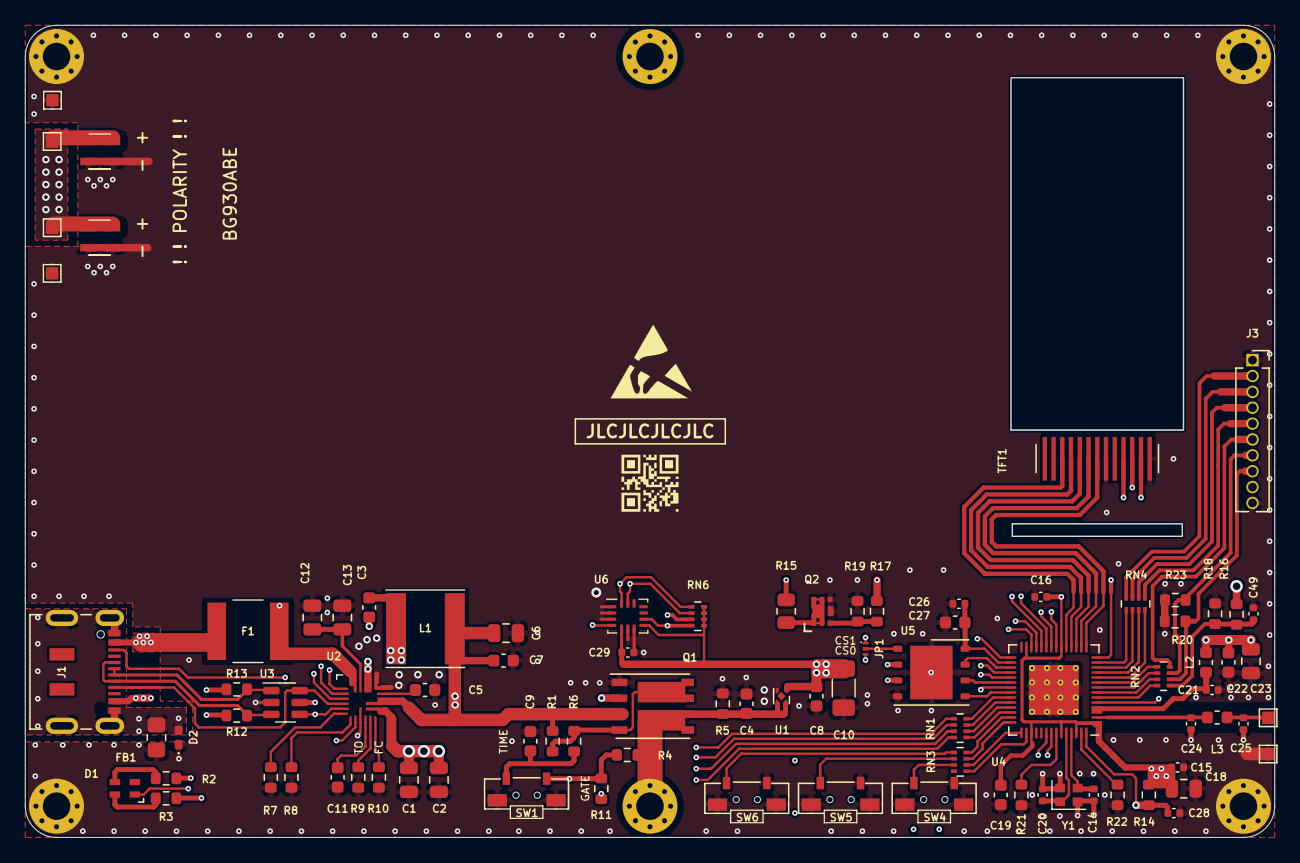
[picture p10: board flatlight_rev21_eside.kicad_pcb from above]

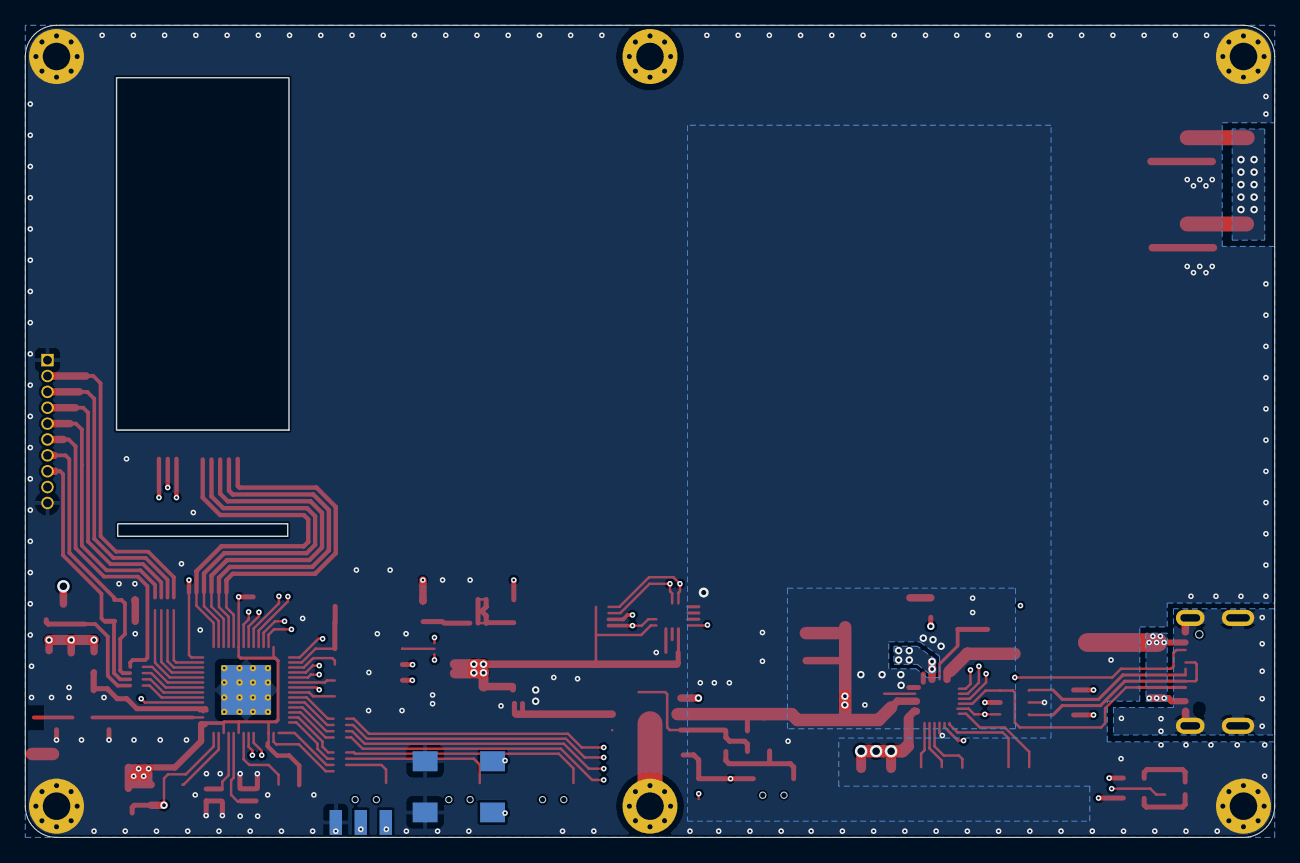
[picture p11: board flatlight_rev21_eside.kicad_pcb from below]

Board: 4 copper layers, 100.0 x 65.0 mm, 102 parts (5 on the bottom side), 92 nets.

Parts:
BT1: lipo_sams_BG930ABE; lipo_samsung_BG930ABE_double
C1, C2, C6, C12, C18, C23: 10µF; C_0805_2012Metric
C3: 100nF; C_0603_1608Metric
C4, C7, C8, C9, C19, C22, C27: 1µF; C_0603_1608Metric
C5, C11: 2.2µF; C_0603_1608Metric
C10: 10µF; C_1206_3216Metric_Pad1.33x1.80mm_HandSolder
C13: 22µF; C_0805_2012Metric
C14, C20: 10pF; C_0402_1005Metric
C15, C16, C21, C26, C28, C29, C49: 100nF; C_0402_1005Metric
C24, C25: 4,7 pF; C_0402_1005Metric
D1: LED_ABRG; 0606_ARGB_LED
D2: ESD9B5.0ST5G; D_0402_1005Metric_Pad0.77x0.64mm_HandSolder
F1: Polyfuse_Small; FUSE_littlefuse_2016-4.1x5.2mm
FB1: FerriteBead_Small; R_0805_2012Metric_Pad1.20x1.40mm_HandSolder
H1, H2, H3, H4, H5, H6: MountingHole_Pad; MountingHole_2.2mm_M2_Pad_Via
J1: USB_C_Receptacle_USB2.0; USB_C_Receptacle_JAE_DX07S016JA1R1500
J2: G-T-R; 01x03_smd_1mmx2mm_pad
J3: B2B_eside; PinSocket_1x10_P1.27mm_Vertical
JP1: SolderJumper_3_Open; microbridge
L1: 1µH; L_Taiyo-Yuden_NR-60xx
L2: 1µH; L_0603_1608Metric
L3: 1.8 nH; L_0603_1608Metric
Q1: DMC1016UPD; PowerDI5060-8
Q2: DMN2022-UFDF7; U-DFN2020-6 (Type F)
R1, R4, R14, R21, R22: 10kΩ; R_0603_1608Metric
R2, R3: 1KΩ; R_0603_1608Metric
R5: 10kΩ (depending on caps); R_0603_1608Metric
R6: 100kΩ; R_0603_1608Metric
R7, R8: 20kΩ; R_0603_1608Metric
R9: 10KΩ(150mA_TO); R_0603_1608Metric
R10: 10KΩ(1.5A_FC); R_0603_1608Metric
R11: 0 Ω; R_0603_1608Metric
R12, R13: 22Ω; R_0603_1608Metric
R15: 14Ω; R_0805_2012Metric
R16, R18, R19: 1MΩ; R_0603_1608Metric
R17: 1kΩ; R_0603_1608Metric
R20, R23: 10 kΩ; R_0603_1608Metric
RN1, RN2, RN3: 0Ω; R_Array_Concave_4x0402
RN4: 1kΩ; R_Array_Concave_4x0402
RN6: 10KΩ; R_Array_Concave_4x0402
SW1, SW4, SW5, SW6: BTN_PWR; white_nano_smd_switch
SW2: BT; SW_SPST_EVQPE1
SW3: RST; SW_SPST_EVQPE1
TFT1: OLED_ST7735_0.9inch_SPI_13pin; TFT_ST7735_0,96_160x80_folded
TP6: ANT_H; TestPoint_Pad_1.0x1.0mm
TP8: ANT_GND; TestPoint_Pad_1.0x1.0mm
TP11, TP12: GND; TestPoint_Pad_1.0x1.0mm
TP13, TP14: +BATT; TestPoint_Pad_1.0x1.0mm
U1: NCP167-XDFN4; UDFN-4-1EP_1x1mm_P0.65mm_EP0.48x0.48mm
U2: MAX77751; max77751
U3: USBLC6-4SC6; SOT-23-6
U4: ESP32-S2; QFN-56-1EP_7x7mm_P0.4mm_EP5.6x5.6mm_ThermalVias
U5: AT25xxx-MA; WSON-8-1EP_6x5mm_P1.27mm_EP3.4x4.3mm
U6: LSM6DS3; Bosch_LGA-14_3x2.5mm_P0.5mm
Y1: 40MHz; Crystal_SMD_2016-4Pin_2.0x1.6mm_smallpads
logo1: logo_qrtag; logo_QR_url_git_catlight
logo2: logo_JLC; JLC-SERIAL
logo6: logo_esd; ESD-Logo_6.6x6mm_SilkScreen
logo8: logo_heart; logo_heart3
logo10: logo_CATLIGHT; logo_catlightMK2_small

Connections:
+3V3: C8.2, C10.2, C15.2, C16.2, C18.2, C19.2, C22.2, C23.2, C29.2, J3.9, L2.1, R14.2, RN6.5 (R4.2), RN6.6 (R3.2), RN6.7 (R2.2), RN6.8 (R1.2), TFT1.10 (VCC), TFT1.12 (LEDA), U1.1 (OUT), U4.1 (VDDA), U4.20 (VDD3P3_RTC), U4.27 (VDD3P3_RTC_IO), U4.45 (VDD3P3_CPU), U4.51 (VDDA), U4.54 (VDDA), U6.5 (VDDIO), U6.8 (VDD)
+BATT: BT1.7 (+), BT1.8 (+), C1.2, C2.2, R16.2, TP13.1, TP14.1, U2.13 (BATT), U2.14 (BATT)
ADC_BATV: C49.1, R16.1, R18.2, RN2.5 (R4.2)
BNT_DIG1: RN3.5 (R4.2), SW6.2
BNT_DIG2: RN3.6 (R3.2), SW5.2
BNT_DIG3: RN3.7 (R2.2), SW4.2
CC1: J1.A5 (CC1), U2.5 (CC1), U3.4 (I/O3)
CC2: J1.B5 (CC2), U2.4 (CC2), U3.6 (I/O4)
D+: J1.A6 (D+), J1.B6 (D+), R13.1, U3.1 (I/O1)
D-: J1.A7 (D-), J1.B7 (D-), R12.1, U3.3 (I/O2)
DISP_BACKLIGHT: R17.1, U4.14 (RTC_GPIO9,___GPIO9,___TOUCH9,___ADC1_CH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)
DISP_CLK: TFT1.4 (SCK), U4.18 (RTC_GPIO13,__GPIO13,__TOUCH13,__ADC2_CH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)
DISP_CS: TFT1.7 (CS), U4.15 (RTC_GPIO10,__GPIO10,__TOUCH10,__ADC1_CH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)
DISP_DATA: TFT1.3 (MOSI), U4.19 (RTC_GPIO14,__GPIO14,__TOUCH14,__ADC2_CH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)
DISP_DC: TFT1.5 (RS), U4.17 (RTC_GPIO12,__GPIO12,__TOUCH12,__ADC2_CH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)
DISP_RESET: TFT1.6 (RES), U4.16 (RTC_GPIO11,__GPIO11,__TOUCH11,__ADC2_CH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)
EN: C28.1, R14.1, SW3.1, U4.56 (CHIP_PU)
ENBST: RN1.5 (R4.2), U2.8 (ENBST)
ES_FLASH_EN: J3.3, RN4.7 (R2.2)
ES_JS_LED_NTC: J3.8, R20.2, RN2.6 (R3.2)
ES_LED_PWM: J3.2, RN4.8 (R1.2)
ES_TORCH_EN: J3.4, RN4.6 (R3.2)
ES_WS_LDAT: J3.5, RN4.5 (R4.2)
ES_WS_POWER: J3.6, RN2.8 (R1.2)
ES_XP_LED_NTC: J3.7, R23.2, RN2.7 (R2.2)
GND: BT1.5 (-), BT1.6 (-), C1.1, C2.1, C4.1, C5.2, C6.1, C7.1, C8.1, C9.2, C10.1, C11.2, C12.2, C13.2, C14.2, C15.1, C16.1, C18.1, C19.1, C20.1, C21.1, C22.1, C23.1, C24.1, C25.1, C26.1, C27.1, C28.2, C29.1, C49.2, D2.1 (A1), FB1.1, H2.1, H3.1, H4.1, H5.1, J2.1, J3.1, J3.10, Q1.1 (S), Q2.2 (S), R5.2, R7.2, R8.2, R9.1, R10.2, R18.1, R19.1, R20.1, R21.1, R22.1, R23.1, SW1.3, SW2.2, SW3.2, SW4.1, SW4.3, SW5.1, SW5.3, SW6.1, SW6.3, TFT1.8 (GND), TFT1.13 (GND), TP8.1, TP11.1, TP12.1, U1.2 (GND), U1.5 (GND), U2.9 (GND), U2.18 (PGND), U2.19 (PGND), U3.2 (GND), U4.57 (GND), U5.4 (GND), U5.9 (GND), U6.1 (SDO/SA0), U6.2 (SDX), U6.3 (SCX), U6.6 (GND), U6.7 (GND), Y1.2, Y1.4
GNDPWR: D2.2 (A2), FB1.2, J1.A1 (GND), J1.A12 (GND), J1.B1 (GND), J1.B12 (GND), J1.S1 (SHIELD)
GPIO0: SW2.1, U4.5 (RTC_GPIO0,___GPIO0)
GPIO45: R21.2, U4.50 (GPIO45)
GPIO46: R22.2, U4.55 (GPIO46)
IMU_INT1: RN6.3 (R3.1), U4.22 (RTC_GPIO16,__GPIO16,__U0CTS,ADC2_CH5,__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), U6.4 (INT1)
IMU_INT2: RN6.4 (R4.1), U4.21 (RTC_GPIO15,__GPIO15,__U0RTS,ADC2_CH4,__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), U6.9 (INT2)
INOK: R2.2, RN1.7 (R2.2), U2.2 (INOKB)
LX: C3.2, L1.2, U2.20 (LX), U2.21 (LX)
unnamed: C3.1, U2.1 (BST)
unnamed: C5.1, U2.17 (PVL)
unnamed: C9.1, R6.2, SW1.2
unnamed: C11.1, U2.10 (VDD)
unnamed: C12.1, C13.1, U2.22 (BYP)
unnamed: C21.2, L2.2, U4.3 (VDD3P3), U4.4 (VDD3P3)
unnamed: C25.2, L3.1, TP6.1
unnamed: D1.3 (RK), R3.1
unnamed: D1.4 (GK), R2.1
unnamed: F1.1, J1.A4 (VBUS), J1.A9 (VBUS), J1.B4 (VBUS), J1.B9 (VBUS)
unnamed: JP1.2 (C), U5.1 (~CS)
unnamed: Q1.2 (G), R4.2, R11.1, SW1.1
unnamed: Q1.4 (G), Q1.7 (D), Q1.8 (D), R1.2, R6.1
unnamed: Q2.1 (D), R15.2
unnamed: Q2.3 (G), R17.2, R19.2
unnamed: R7.1, U2.6 (DP)
unnamed: R8.1, U2.7 (DN)
unnamed: R9.2, U2.11 (ITOPOFF)
unnamed: R10.1, U2.12 (IFAST)
unnamed: R15.1, TFT1.11 (LEDK)
unnamed: RN1.1 (R1.1), U4.40 (SPIIO7,GPIO36,__FSPICLK)
unnamed: RN1.2 (R2.1), U4.39 (SPIIO6,GPIO35,__FSPID)
unnamed: RN1.3 (R3.1), U4.38 (SPIIO5,GPIO34,__FSPICS0)
unnamed: RN1.4 (R4.1), U4.37 (SPIIO4,GPIO33,__FSPIHD)
unnamed: RN2.1 (R1.1), U4.9 (RTC_GPIO4,___GPIO4,___TOUCH4,___ADC1_CH3)
unnamed: RN2.2 (R2.1), U4.8 (RTC_GPIO3,___GPIO3,___TOUCH3,___ADC1_CH2)
unnamed: RN2.3 (R3.1), U4.7 (RTC_GPIO2,___GPIO2,___TOUCH2,___ADC1_CH1)
unnamed: RN2.4 (R4.1), U4.6 (RTC_GPIO1,___GPIO1,___TOUCH1,___ADC1_CH0)
unnamed: RN3.1 (R1.1), U4.44 (MTDO,GPIO40,__CLK_OUT2)
unnamed: RN3.2 (R2.1), U4.43 (MTCK,GPIO39,__CLK_OUT3)
unnamed: RN3.3 (R3.1), U4.42 (GPIO38,__FSPIWP)
unnamed: RN3.4 (R4.1), U4.41 (SPIDQS,GPIO37,__FSPIQ)
unnamed: RN4.1 (R1.1), U4.13 (RTC_GPIO8,___GPIO8,___TOUCH8,___ADC1_CH7)
unnamed: RN4.2 (R2.1), U4.12 (RTC_GPIO7,___GPIO7,___TOUCH7,___ADC1_CH6)
unnamed: RN4.3 (R3.1), U4.11 (RTC_GPIO6,___GPIO6,___TOUCH6,___ADC1_CH5)
unnamed: RN4.4 (R4.1), U4.10 (RTC_GPIO5,___GPIO5,___TOUCH5,___ADC1_CH4)
PWRMAIN_SW: R11.2, RN1.8 (R1.2)
RX: J2.3, U4.48 (U0TXD,GPIO43,__CLK_OUT1)
SCL: RN6.2 (R2.1), U4.23 (TC_GPIO17,__GPIO17,__U1TXD,ADC2_CH6,__D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), U6.13 (SCL)
SDA: RN6.1 (R1.1), U4.24 (RTC_GPIO18,__GPIO18,__U1RXD,ADC2_CH7,__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), U6.14 (SDA)
SPICLK: U4.34 (SPICLK,GPIO30), U5.6 (SCK)
SPICS0: JP1.3 (B), U4.33 (SPICS0,GPIO29)
SPICS1: JP1.1 (A), U4.29 (SPICS1,GPIO26)
SPID: U4.36 (SPID,GPIO32), U5.5 (MOSI)
SPIHD: U4.31 (SPIHD,GPIO27), U5.7 (~HOLD)
SPIQ: U4.35 (SPIQ,GPIO31), U5.2 (MISO)
SPIWP: U4.32 (SPIWP,GPIO28), U5.3 (~WP)
STAT: R3.2, RN1.6 (R3.2), U2.3 (STAT)
SYS: C6.2, C7.2, D1.1 (A), L1.1, Q1.3 (1), R1.1, U2.15 (SYS), U2.16 (SYS)
SYSOUT: C4.2, H1.1, H6.1, Q1.5 (D), Q1.6 (D), R4.1, R5.1, U1.3 (EN), U1.4 (IN)
TX: J2.2, U4.49 (U0RXD,GPIO44,__CLK_OUT2)
U_N: R12.2, U4.25 (RTC_GPIO19,__GPIO19,__U1RTS,ADC2_CH8,__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)
U_P: R13.2, U4.26 (RTC_GPIO20,__GPIO20,__U1CTS,ADC2_CH9,__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)
VBUS: F1.2, U2.23 (VBUS), U2.24 (VBUS), U3.5 (VBUS)
VDD_SPI: C26.2, C27.2, U4.30 (VDD_SPI), U5.8 (VCC)
XTAL_N: C20.2, U4.52 (XTAL_N), Y1.1
XTAL_P: C14.1, U4.53 (XTAL_P), Y1.3
radio: C24.2, L3.2, U4.2 (LNA_IN)

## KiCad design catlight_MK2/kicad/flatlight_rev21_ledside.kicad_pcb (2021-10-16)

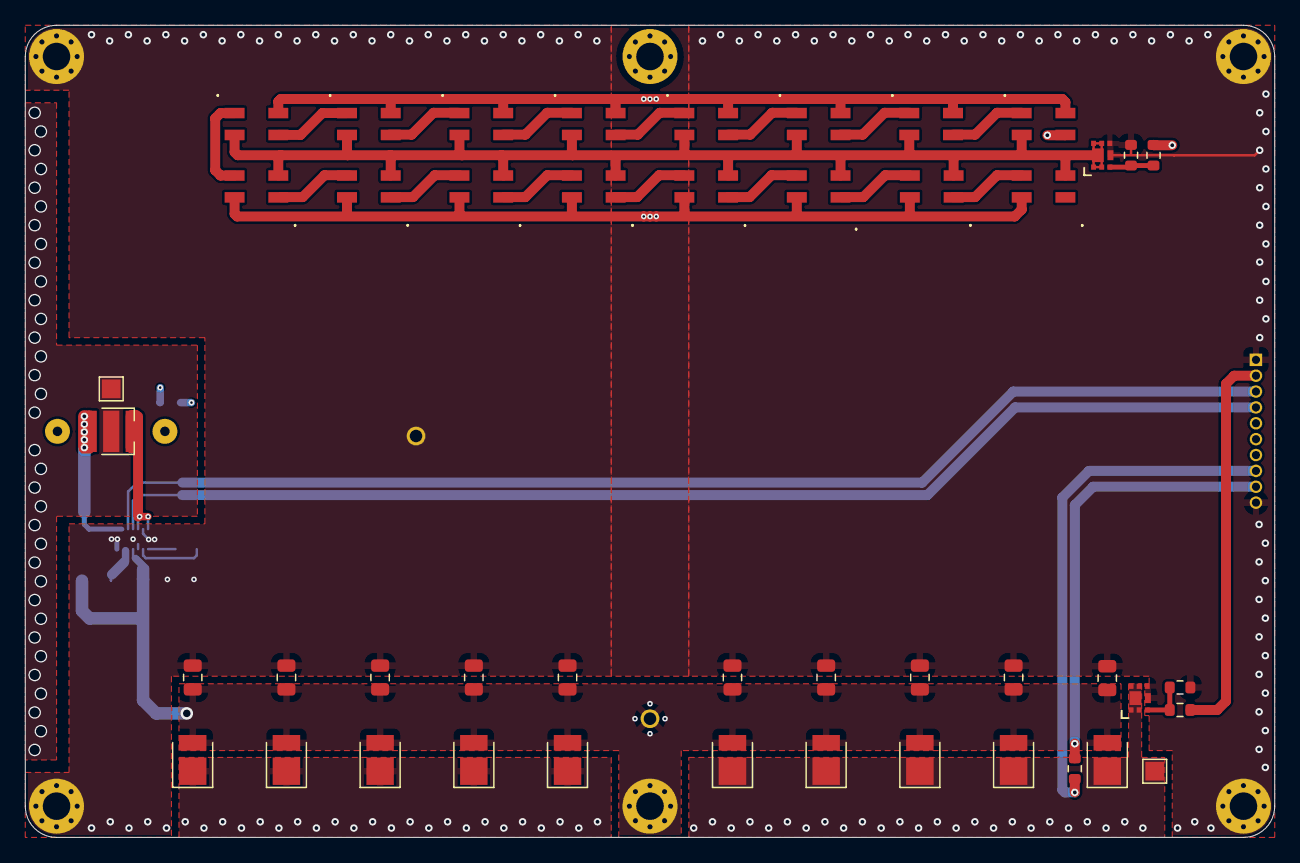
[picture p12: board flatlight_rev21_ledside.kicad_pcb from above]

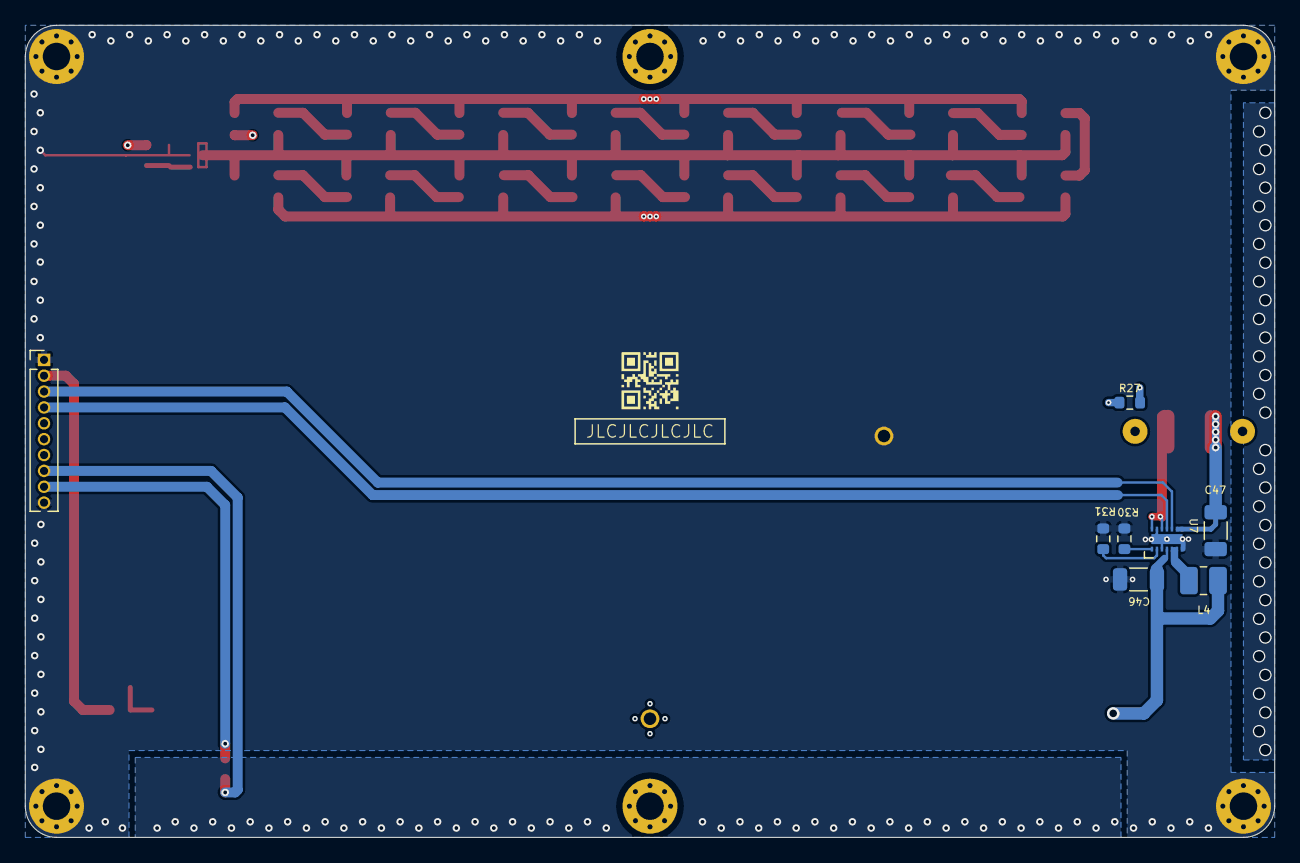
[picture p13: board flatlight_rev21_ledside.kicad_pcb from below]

Board: 4 copper layers, 100.0 x 65.0 mm, 67 parts (10 on the bottom side), 35 nets.

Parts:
C30, C31, C32, C33, C34, C35, C36, C37, C38, C39: 10µF; C_0805_2012Metric
C46: 22µF; C_1206_3216Metric
C47: 10µF; C_1206_3216Metric
D3, D4, D5, D6, D7, D8, D9, D10, D11, D12, D13, D14, D15, D16, D17, D18: SK6812MINI; LED_SK6812MINI
D19, D20, D21, D22, D23, D24, D25, D26, D27, D28: LED; LED_PLCC_2835
D35: LED_Cree_XPP; LED_Cree-XHP35
H7: thole1; plated_hole_1mm
H14: thole8; plated_hole_1mm
H15, H16, H17, H18, H19, H20: MountingHole_Pad; MountingHole_2.2mm_M2_Pad_Via
J4: B2B_ledside; PinHeader_1x10_P1.27mm_Vertical
L4: 1µH; L_1008_2520Metric_Pad1.43x2.20mm_HandSolder
Q3, Q4: DMN2022-UFDF7; U-DFN2020-6 (Type F)
R24, R28: 1kΩ; R_0603_1608Metric
R25, R29: 1MΩ; R_0603_1608Metric
R26, R27: NTC 10 kΩ; R_0603_1608Metric
R30: 37.5kΩ; R_0603_1608Metric
R31: 12kΩ; R_0603_1608Metric
TP9, TP10: TestPoint; TestPoint_Pad_1.5x1.5mm
U7: LDRV_DIO5180; DFN-14-2x3mm
lense1: Lense_Mount; LENS_LEDIL_C12491_siri_diff
logo1: logo_qrtag; logo_QR_url_git_catlight
logo5: logo_JLC; JLC-SERIAL
logo9: logo_LWarn; logo_lightwarn_large
logo10: logo_CATLIGHT; logo_catlightMK2_small

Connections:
+3V3: J4.9, R26.1, R27.1
GND: C30.2, C31.2, C32.2, C33.2, C34.2, C35.2, C36.2, C37.2, C38.2, C39.2, C46.1, C47.1, H14.1, H17.1, H18.1, H19.1, H20.1, J4.1, J4.10, Q3.2 (S), Q4.2 (S), R25.1, R29.1, R30.1, R31.1, U7.3 (AGND), U7.7 (PGND), U7.13 (AGND), U7.15 (AGND)
LS_FLASH_EN: J4.3, U7.10 (ENF)
LS_JS_LED_NTC: J4.8, R26.2
LS_LED_PWM: J4.2, R28.1
LS_PWM_PWR: D19.1 (K), D20.1 (K), D21.1 (K), D22.1 (K), D23.1 (K), D24.1 (K), D25.1 (K), D26.1 (K), D27.1 (K), D28.1 (K), Q4.1 (D), TP9.1
LS_SYS: C30.1, C31.1, C32.1, C33.1, C34.1, C35.1, C36.1, C37.1, C38.1, C39.1, C46.2, D3.4 (VDD), D4.4 (VDD), D5.4 (VDD), D6.4 (VDD), D7.4 (VDD), D8.4 (VDD), D9.4 (VDD), D10.4 (VDD), D11.4 (VDD), D12.4 (VDD), D13.4 (VDD), D14.4 (VDD), D15.4 (VDD), D16.4 (VDD), D17.4 (VDD), D18.4 (VDD), D19.2 (A), D20.2 (A), D21.2 (A), D22.2 (A), D23.2 (A), D24.2 (A), D25.2 (A), D26.2 (A), D27.2 (A), D28.2 (A), H7.1, H15.1, H16.1, L4.1, U7.4 (VIN)
LS_TORCH_EN: J4.4, U7.11 (ENM)
LS_WS_LDAT: D3.3 (DIN), J4.5
LS_WS_POWER: J4.6, R24.2
LS_XP_LED_NTC: J4.7, R27.2
unnamed: C47.2, D35.2 (K), U7.8 (VOUT), U7.9 (VOUT)
unnamed: D3.1 (DOUT), D4.3 (DIN)
unnamed: D4.1 (DOUT), D5.3 (DIN)
unnamed: D5.1 (DOUT), D6.3 (DIN)
unnamed: D6.1 (DOUT), D7.3 (DIN)
unnamed: D7.1 (DOUT), D8.3 (DIN)
unnamed: D8.1 (DOUT), D9.3 (DIN)
unnamed: D10.1 (DOUT), D11.3 (DIN)
unnamed: D9.1 (DOUT), D10.3 (DIN)
unnamed: D11.1 (DOUT), D12.3 (DIN)
unnamed: D12.1 (DOUT), D13.3 (DIN)
unnamed: D13.1 (DOUT), D14.3 (DIN)
unnamed: D14.1 (DOUT), D15.3 (DIN)
unnamed: D15.1 (DOUT), D16.3 (DIN)
unnamed: D16.1 (DOUT), D17.3 (DIN)
unnamed: D17.1 (DOUT), D18.3 (DIN)
unnamed: D35.1 (A), U7.12 (D1), U7.14 (D2)
unnamed: L4.2, U7.5 (SW), U7.6 (SW)
unnamed: Q3.3 (G), R24.1, R25.2
unnamed: Q4.3 (G), R28.2, R29.2
unnamed: R30.2, U7.1 (RSETM)
unnamed: R31.2, U7.2 (RSETF)
PAD: D35.3 (PAD), TP10.1
WS_GNDBUS: D3.2 (VSS), D4.2 (VSS), D5.2 (VSS), D6.2 (VSS), D7.2 (VSS), D8.2 (VSS), D9.2 (VSS), D10.2 (VSS), D11.2 (VSS), D12.2 (VSS), D13.2 (VSS), D14.2 (VSS), D15.2 (VSS), D16.2 (VSS), D17.2 (VSS), D18.2 (VSS), Q3.1 (D)

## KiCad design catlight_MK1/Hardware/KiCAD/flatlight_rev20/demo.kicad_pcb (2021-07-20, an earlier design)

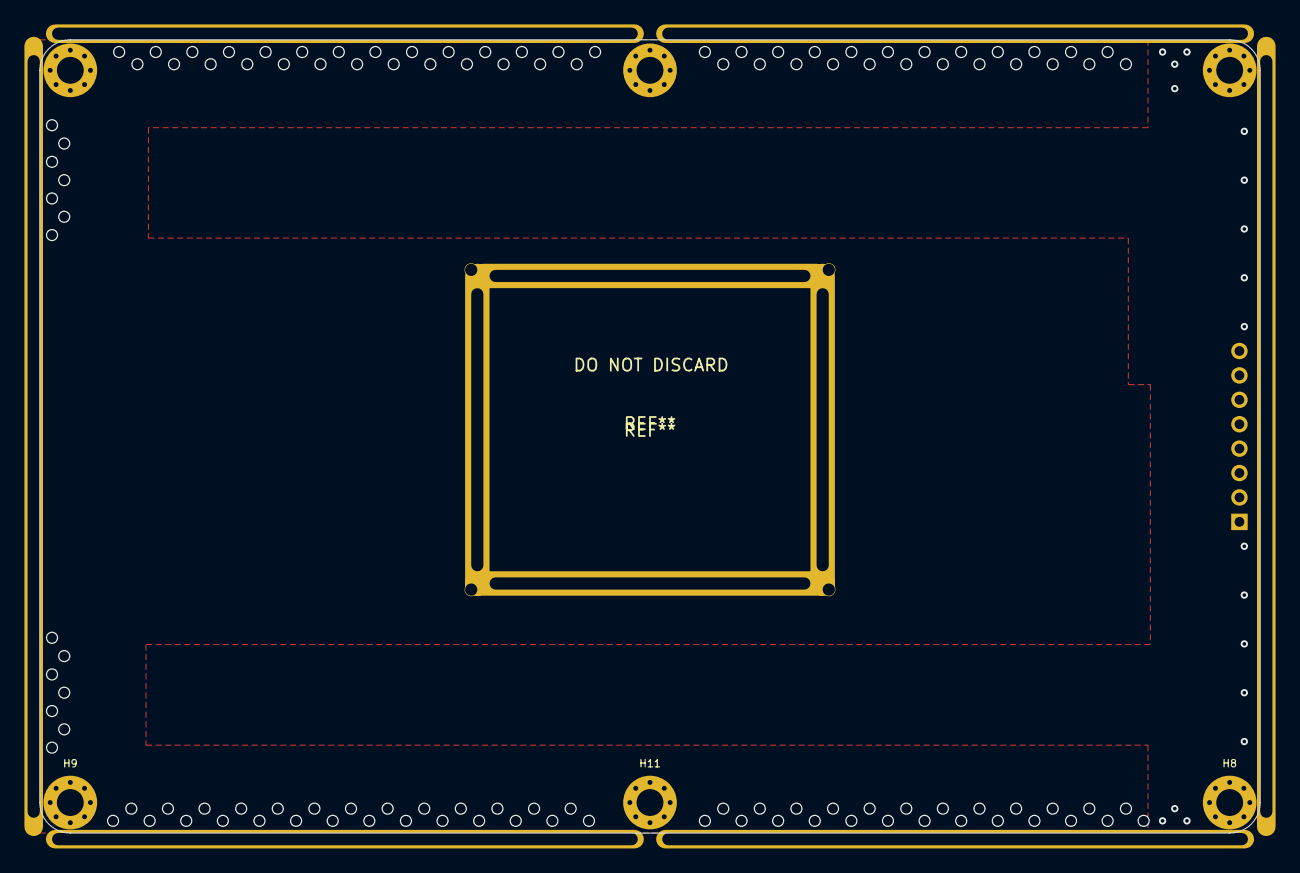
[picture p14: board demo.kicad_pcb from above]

Board: 4 copper layers, 100.0 x 65.0 mm, 7 parts (1 on the bottom side), 2 nets.

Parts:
H7, H8, H9, H10, H11, H12: MountingHole_Pad; MountingHole_2.2mm_M2_Pad_Via
J5: Conn_01x08_Female; PinHeader_1x08_P2.00mm_Vertical

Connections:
+BATT: H7.1, H11.1
GND: H8.1, H9.1, H10.1, H12.1, J5.1, J5.5

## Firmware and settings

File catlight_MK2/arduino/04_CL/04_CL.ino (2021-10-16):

/* Catlight rev 2
 *  by http://github.com/specs32/catlight
 *  Hard and Software is licensend under CC-NC-BY-SA
 *
 *  ESIDE :
 *
 *  ESP32-S2 (@ 240 MHz with 40 MHz Crystal & 4MB Flash)
 *  MAX77751 Charger (INOK - ITOPOFF - STAT - ENBST)
 *  Navigation  (3 Buttons)
 *  1 TFT - 1.2" SPI Color Display 
 *  1 IMU - Gyro Accel - (LSM6DS3)
 *
 *  LEDSIDE :
 *
 *  10 x SK6812 - 3535  8x Light leds (0-7) & 2x status-leds (8+9) (GND PWR Mosfet switched)
 *  16 Cree J-Series HighPower (@ 5600 Kelvin) (GND PWR PWM switched)
 *  1 NTC
 *  
 *  
 */




// USB







// WIFI
 

/**
 * OnDemandNonBlocking.ino
 * example of running the webportal or configportal manually and non blocking
 * trigger pin will start a webportal for 120 seconds then turn it off.
 * startAP = true will start both the configportal AP and webportal
 */
#include <WiFiManager.h> // https://github.com/tzapu/WiFiManager
bool TRIGGER_PIN = HIGH;
WiFiManager wm;
WiFiManagerParameter custom_field; // global param ( for non blocking w params )


unsigned int  timeout   = 600; // seconds to run for
unsigned int  startTime = millis();
bool portalRunning      = false;
bool startAP            = false; // start AP and webserver if true, else start only webserver



// PIXEL
#include <Adafruit_NeoPixel.h>

#define LED_PIN    5

// How many NeoPixels are attached to the Arduino?
#define LED_COUNT 16

Adafruit_NeoPixel strip(LED_COUNT, LED_PIN, NEO_GRB + NEO_KHZ800);


uint16_t PIXBRI = 50;                                         // Pixel brightness


// CHARGER PINS
#define INOK 35
#define ENBST 33
#define CHGSTAT 34


// IMU
#include "SparkFunLSM6DS3.h"                                  // please check out https://github.com/sparkfun/SparkFun_LSM6DS3_Arduino_Library for license and such
LSM6DS3 myIMU( I2C_MODE, 0x6A );                              //I2C device address 0x6A

int16_t accelx;
int16_t accely;
int16_t accelz;
int16_t imutemp;
int16_t imutemph;
int16_t imutempl;

// INT 1
const int int1Pin = 16;                                        //Use pin 2 for int.0 on uno
uint8_t int1Status = 0;
uint8_t t_toggle = 0;                                         // tap toggle
uint8_t t_toggle_last = 0;
uint8_t dt_toggle = 0;                                        // dt toggle
uint8_t dt_toggle_last = 0;

// INT 2
const int int2Pin = 15;                                        //Use pin 2 for int.0 on uno
uint8_t int2Status = 0;
uint8_t wu_toggle = 0;
uint8_t sl_toggle = 1;

//// CHECK !!
//// BUTTON PINS

const int BUTTON_UP = 39;                                    // define the up button pin
const int BUTTON_ENTER = 38;
const int BUTTON_DOWN = 37;                                  // define the down button pin


#define LEDC_PWMCHANNEL     0
#define LEDC_TFTCHANNEL     1
#define LEDC_TORCHANNEL     2
#define LEDC_FLACHANNEL     3

#define LEDC_TORTIMER   10
#define LEDC_TORFREQ     1000000

#define LEDC_FLATIMER   10
#define LEDC_FLAFREQ     1000000


#define LEDC_PWMTIMER   10
#define LEDC_PWMFREQ     1000000

#define LEDC_TFTTIMER   10
#define LEDC_TFTFREQ     1000000

#define TORLED_PIN            6
#define FLALED_PIN            7
#define PWMLED_PIN            8
#define TFTPWR_PIN            9
#define PIXPWR_PIN            4


// CONSTRAINS to the leds
uint16_t TFTPWM = 505;
uint16_t LIGHTPWMLIMIT = 220;                                  // PWMLIMIT FOR THE FULLY CHARGED LIPO !!!! 
uint16_t LIGHTMAXTEMP = 50;                                   // (when to STEP down !) Depends very strong on the thermal connection between LED and NTC... 
uint16_t LIGHTCRITTEMP = 60;                                   // (when to SHUT down  !) compensate for overshoot ...
uint16_t LIGHTSTATE = 0;                                       // LIGHT @ 1-(PWMLIMIT)
uint16_t TORCHPWMLIMIT = 250;
uint16_t TORCHSTATE = 0;                                       // LIGHT @ 1-(PWMLIMIT)
uint16_t Vf_LIGHT = 3000;    
uint16_t FLAMAXTEMP = 50;
uint16_t TORMAXTEMP = 50;


uint16_t bat_full = 4300;                                     // Lipo charged
uint16_t bat_empty = 2850;                                    // Lipo discharged 

// BUTTON SETTINGS
const uint8_t bounceTime = 50;                                // define button debounce
const uint16_t holdTime = 250;                                 // define button hold time
const uint16_t doubleTime = 700;                              // define button doubleclick time
const int TAPTIME = 400;                                // TAP / DT DETECTION TIME



// BUTTON UP
boolean up_lastReading = HIGH;                                // button read value
long up_onTime = 0;                                           // button read ontime
long up_lastSwitchTime = 0;                                   // button switchtime value
uint8_t up_hold = 0;                                          // button hold value
uint8_t up_single = 0;                                        // button single press value

// BUTTON DOWN
boolean down_lastReading = HIGH;                              // button read value
long down_onTime = 0;                                         // button read ontime
long down_lastSwitchTime = 0;                                 // button switchtime value
uint8_t down_hold = 0;                                        // button hold value
uint8_t down_single = 0;


// BUTTON ENTER
boolean enter_lastReading = HIGH;                              // button read value
long enter_onTime = 0;                                         // button read ontime
long enter_lastSwitchTime = 0;                                 // button switchtime value
uint8_t enter_hold = 0;                                        // button hold value
uint8_t enter_single = 0;

                          // define button doubleclick time

// PLASMA FUNCTION
#define qsubd(x, b)  ((x>b)?b:0)                              // Digital unsigned subtraction macro. if result <0, then => 0. Otherwise, take on fixed value.
#define qsuba(x, b)  ((x>b)?x-b:0)                            // Analog Unsigned subtraction macro. if result <0, then => 0



// SPI-DISPLAY
#include <Adafruit_GFX.h>    // Core graphics library
#include <Adafruit_ST7735.h> // Hardware-specific library for ST7735
#include <SPI.h>
#define TFT_CS        10
#define TFT_RST       11 // Or set to -1 and connect to Arduino RESET pin
#define TFT_DC        12 
#define TFT_MOSI   14 // Data out
#define TFT_SCLK  13 // Clock out
Adafruit_ST7735 tft = Adafruit_ST7735(TFT_CS, TFT_DC, TFT_MOSI, TFT_SCLK, TFT_RST);

// Fonts
#include <U8g2_for_Adafruit_GFX.h>
U8G2_FOR_ADAFRUIT_GFX u8g2_for_adafruit_gfx;

#include <SimpleTimer.h>                                      // out of the arduino repo
SimpleTimer TEMPSCHECK;
SimpleTimer BATCHECK;
SimpleTimer AUTOPWMCHECK;

uint16_t tcolor1 = ST77XX_GREEN;
uint16_t tcolor2 = ST77XX_GREEN;
uint16_t tcolor3 = ST77XX_GREEN;
uint16_t HOLD = 0;
uint16_t TOGGLED = 0;
int dt_toggle_old = 0;
uint16_t tetecolor = 0;
int bst_toggle = 0;
int wifi_toggle = 0;




void setup() {

  // serial
  Serial.begin(115200);
  Serial.setDebugOutput(true);
  delay(1000);
  Serial.println("\n Starting");

//  HWSerial.begin(115200);
//  HWSerial.setDebugOutput(true);
//
//  USB.onEvent(usbEventCallback);
//  MSC_Update.onEvent(usbEventCallback);
//  MSC_Update.begin();
//  USBSerial.begin();
//  USB.begin();
//


// WIFI 
 
 

  
  // timers
  TEMPSCHECK.setInterval(1053);                       // call  every x milliseconds
  BATCHECK.setInterval(3001);               
  AUTOPWMCHECK.setInterval(157);     
   
  // i2c
  Wire.begin(18,17);

  u8g2_for_adafruit_gfx.begin(tft);                 // connect u8g2 procedures to Adafruit GFX

  // IMU SETUP
  IMUSTREG();
  
  // setting up the interrupt pins
  pinMode(int1Pin, INPUT);                                       
  attachInterrupt(digitalPinToInterrupt(int1Pin), int1ISR, RISING); 
  pinMode(int2Pin, INPUT);                                      
  attachInterrupt(digitalPinToInterrupt(int2Pin), int2ISR, RISING);

  //define BUTTON pins
  pinMode(BUTTON_UP, INPUT_PULLUP);
  pinMode(BUTTON_DOWN, INPUT_PULLUP);
  pinMode(BUTTON_ENTER, INPUT_PULLUP);

  //define CHARGER pins
  pinMode(ENBST, OUTPUT);           // boost  function
  digitalWrite(ENBST, LOW);         // off by default
  pinMode(INOK, INPUT_PULLUP);      // input source detection high = good | high = boost | off = no VBUS IO
  pinMode(CHGSTAT, INPUT_PULLUP);   // charger status 500ms pulse = charging | off=done

  // define Pins for NEOPIXEL PWR MOSFET and setup pixels
  pinMode(PIXPWR_PIN, OUTPUT);
  digitalWrite(PIXPWR_PIN, HIGH);     // on by default
  strip.begin();           // INITIALIZE NeoPixel strip object (REQUIRED)
  strip.show();            // Turn OFF all pixels ASAP
  strip.setBrightness(PIXBRI); // Set BRIGHTNESS to about 1/5 (max = 255)

  // Setup  Torch  // Setup  Flash
  ledcSetup(LEDC_TORCHANNEL, LEDC_TORFREQ, LEDC_TORTIMER);
  ledcAttachPin(TORLED_PIN, LEDC_TORCHANNEL);  
  ledcWrite(LEDC_TORCHANNEL, 0);

  ledcSetup(LEDC_FLACHANNEL, LEDC_FLAFREQ, LEDC_FLATIMER);
  ledcAttachPin(FLALED_PIN, LEDC_FLACHANNEL);  
  ledcWrite(LEDC_FLACHANNEL, 0);

  // Setup  Main LEDs
  ledcSetup(LEDC_PWMCHANNEL, LEDC_PWMFREQ, LEDC_PWMTIMER);
  ledcAttachPin(PWMLED_PIN, LEDC_PWMCHANNEL);
  ledcWrite(LEDC_PWMCHANNEL, LIGHTSTATE);
  

  // Setup and Turn on TFT 
  ledcSetup(LEDC_TFTCHANNEL, LEDC_TFTFREQ, LEDC_TFTTIMER);  // ledc for Dimming .. we have a mosfet there
  ledcAttachPin(TFTPWR_PIN, LEDC_TFTCHANNEL);
  ledcWrite(LEDC_TFTCHANNEL, TFTPWM);
  
  //tft.initR(INITR_MINI160x80);  // Init ST7735S mini display
  
  tft.initR(INITR_GREENTAB);
  tft.setRotation(ST7735_MADCTL_BGR);
  tft.setColRowStart(26, 1);

  tft.invertDisplay(1);
  tft.setRotation(3);
  tft.fillScreen(ST77XX_BLACK);                             // clear the graphcis buffer  

  u8g2_for_adafruit_gfx.setFont(u8g2_font_bubble_tr);  // NICE !!! select u8g2 font from here: https://github.com/olikraus/u8g2/wiki/fntlistall
  u8g2_for_adafruit_gfx.setFontMode(1);                 // use u8g2 transparent mode (this is default)
  u8g2_for_adafruit_gfx.setFontDirection(0);            // left to right (this is default)
  u8g2_for_adafruit_gfx.setForegroundColor(ST77XX_BLACK);      // apply Adafruit GFX color

  // Set ADC Gain and Res
  analogSetPinAttenuation(1, ADC_11db); // ADC_BATV (BAT divider)
  analogSetPinAttenuation(2, ADC_11db); // NTC_PWMLED (top between the LEDS)
  analogSetPinAttenuation(3, ADC_11db); // NTC_BAT / XP_LED (bottom NTC)

}


/* MAIN LOOP */

void loop() {


  wm.process();

  
  CHKBTN();
  CHKIMU();


  if(TEMPSCHECK.isReady()){
    TEMPS();
    TEMPSCHECK.reset();
    }
  
  if(BATCHECK.isReady()){
    BATDISP();
    BATCHECK.reset();
    }
  
 
  if(AUTOPWMCHECK.isReady()){
    AUTOPWM();
    AUTOPWMCHECK.reset();
    }

 


} 

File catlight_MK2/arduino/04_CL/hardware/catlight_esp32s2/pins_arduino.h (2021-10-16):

#ifndef Pins_Arduino_h
#define Pins_Arduino_h

#include <stdint.h>

#define USB_VID             0xc471
#define USB_PID             0x1677
#define USB_MANUFACTURER    "Specs32"
#define USB_PRODUCT         "CATLight"
#define USB_SERIAL 			"002"
#define USB_WEBUSB_ENABLED	false

// Default USB FirmwareMSC Settings
#define USB_FW_MSC_VENDOR_ID 		"ESP32-S2" 		//max 8 chars
#define USB_FW_MSC_PRODUCT_ID 		"Firmware MSC"	//max 16 chars
#define USB_FW_MSC_PRODUCT_REVISION "1.23" 			//max 4 chars
#define USB_FW_MSC_VOLUME_NAME 		"S2-Firmware" 	//max 11 chars
#define USB_FW_MSC_SERIAL_NUMBER 	0x00000000

#define EXTERNAL_NUM_INTERRUPTS 46
#define NUM_DIGITAL_PINS        48
#define NUM_ANALOG_INPUTS       20

#define analogInputToDigitalPin(p)  (((p)<20)?(esp32_adc2gpio[(p)]):-1)
#define digitalPinToInterrupt(p)    (((p)<48)?(p):-1)
#define digitalPinHasPWM(p)         (p < 46)


static const uint8_t TX = 43;
static const uint8_t RX = 44;

static const uint8_t SDA = 8;
static const uint8_t SCL = 9;

static const uint8_t SS    = 34;
static const uint8_t MOSI  = 35;
static const uint8_t MISO  = 37;
static const uint8_t SCK   = 36;

static const uint8_t A0 = 1;
static const uint8_t A1 = 2;
static const uint8_t A2 = 3;
static const uint8_t A3 = 4;
static const uint8_t A4 = 5;
static const uint8_t A5 = 6;
static const uint8_t A6 = 7;
static const uint8_t A7 = 8;
static const uint8_t A8 = 9;
static const uint8_t A9 = 10;
static const uint8_t A10 = 11;
static const uint8_t A11 = 12;
static const uint8_t A12 = 13;
static const uint8_t A13 = 14;
static const uint8_t A14 = 15;
static const uint8_t A15 = 16;
static const uint8_t A16 = 17;
static const uint8_t A17 = 18;
static const uint8_t A18 = 19;
static const uint8_t A19 = 20;

static const uint8_t T1 = 1;
static const uint8_t T2 = 2;
static const uint8_t T3 = 3;
static const uint8_t T4 = 4;
static const uint8_t T5 = 5;
static const uint8_t T6 = 6;
static const uint8_t T7 = 7;
static const uint8_t T8 = 8;
static const uint8_t T9 = 9;
static const uint8_t T10 = 10;
static const uint8_t T11 = 11;
static const uint8_t T12 = 12;
static const uint8_t T13 = 13;
static const uint8_t T14 = 14;

static const uint8_t DAC1 = 17;
static const uint8_t DAC2 = 18;

#endif /* Pins_Arduino_h */

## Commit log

2021-07-20 catlight - MK1
    [demo-B_Cu.gbr, demo-B_Mask.gbr, demo-B_Silkscreen.gbr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]
2021-10-16 catlight - MK2
    [catlight_frame_30.blend, catlight_frame_30.stl, flatlight_rev21.csv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]
